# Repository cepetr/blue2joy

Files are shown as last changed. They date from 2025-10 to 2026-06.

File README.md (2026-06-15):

# 🕹️ Blue2Joy

**Blue2Joy** is an adapter that lets you use modern Bluetooth controllers with Atari 8-bit computers. It emulates **digital joysticks**, **analog paddles**, and supports **bidirectional communication** and much more. Try the live demo: https://cepetr.github.io/blue2joy/main.

While primarily intended for gamepads, the device is not limited to them - in principle, any BLE HID device, such as a keyboard or mouse, can be connected.

> Only devices that fully support the BLE HID over GATT Profile (HOGP) are supported. For this reason many older devices (especially gamepads) are unfortunately not usable with Blue2Joy. See [compatible devices](/doc/compatible-devices.md).

<div>
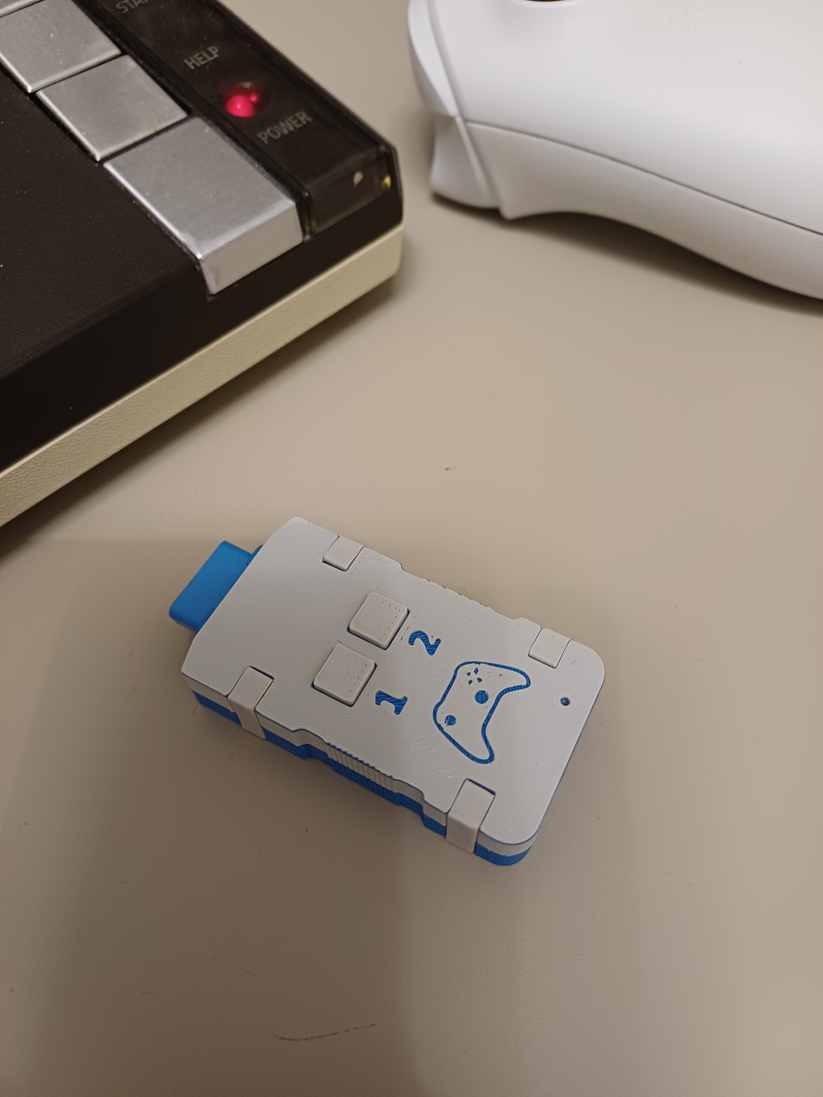
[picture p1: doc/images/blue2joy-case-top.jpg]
  
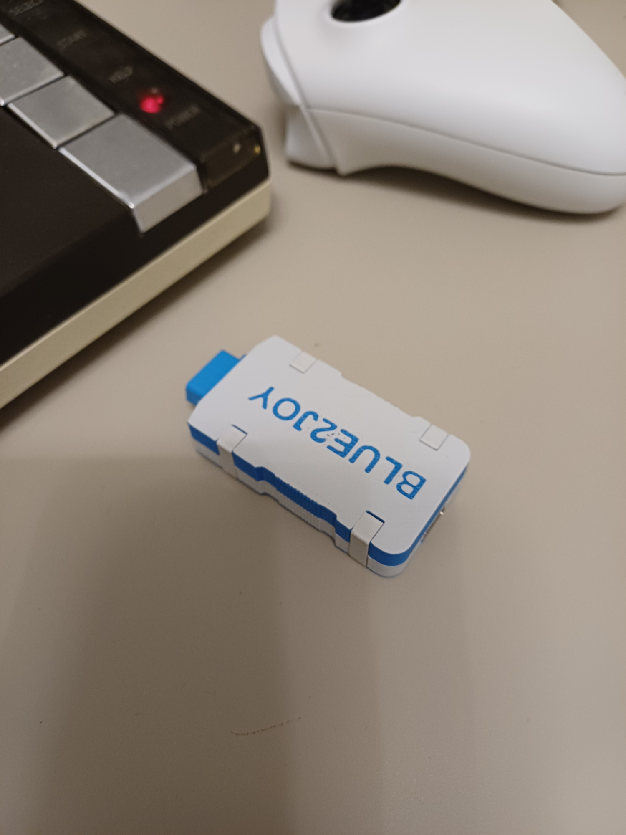
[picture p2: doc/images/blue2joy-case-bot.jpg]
  
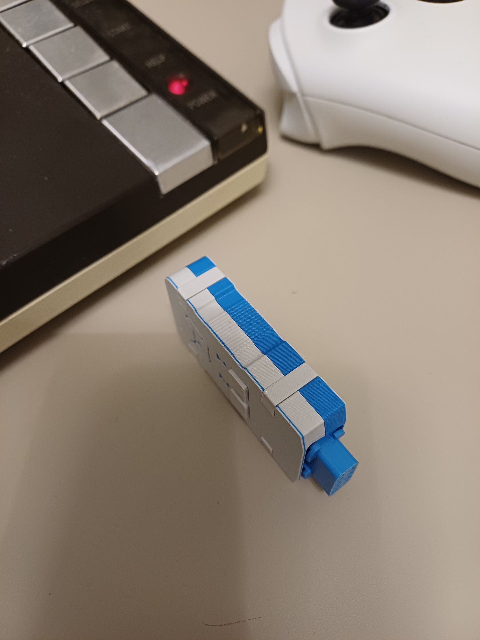
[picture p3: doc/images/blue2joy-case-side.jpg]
  
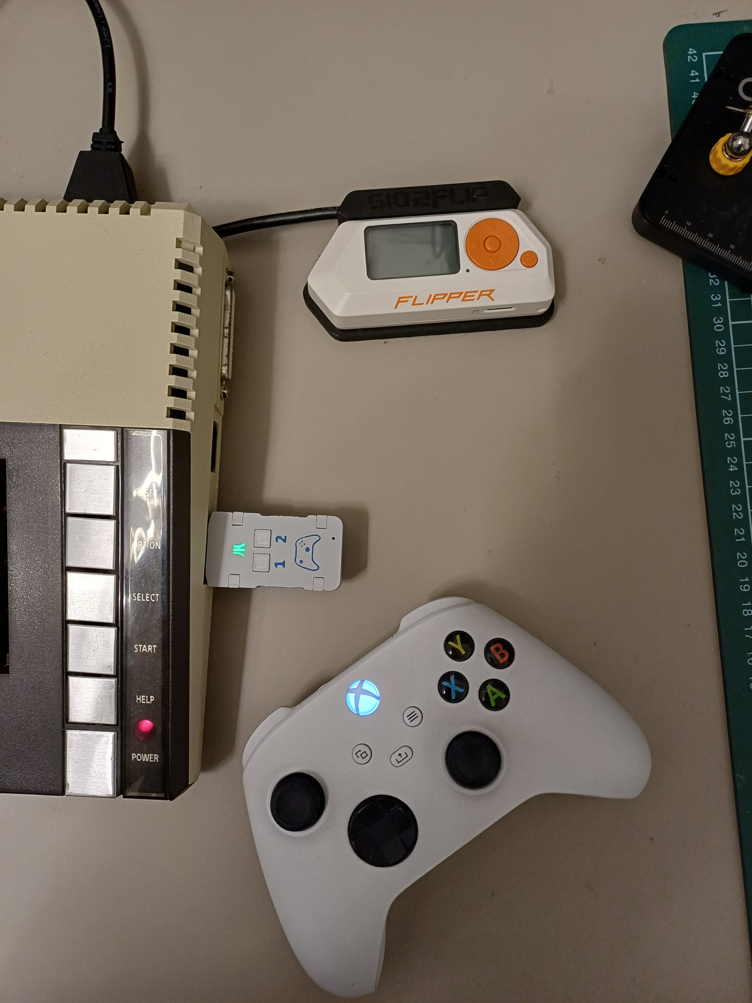
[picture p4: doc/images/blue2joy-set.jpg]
  
</div>

<div>
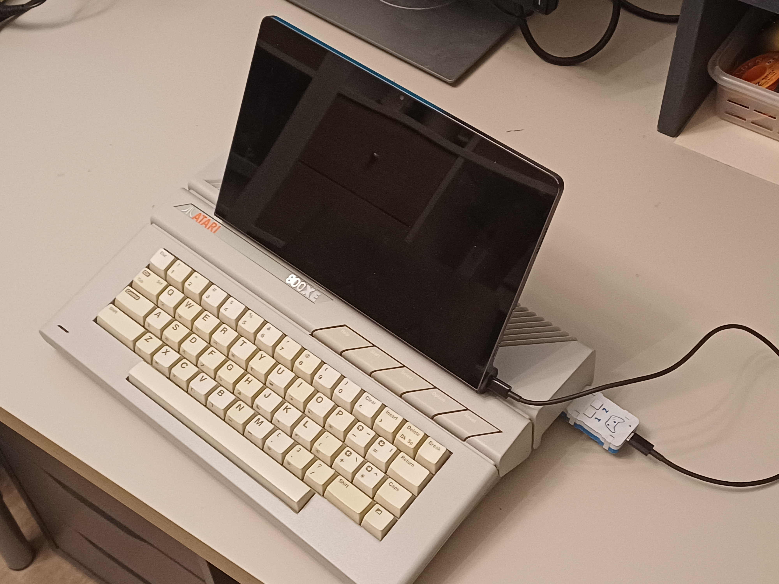
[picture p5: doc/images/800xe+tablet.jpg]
  
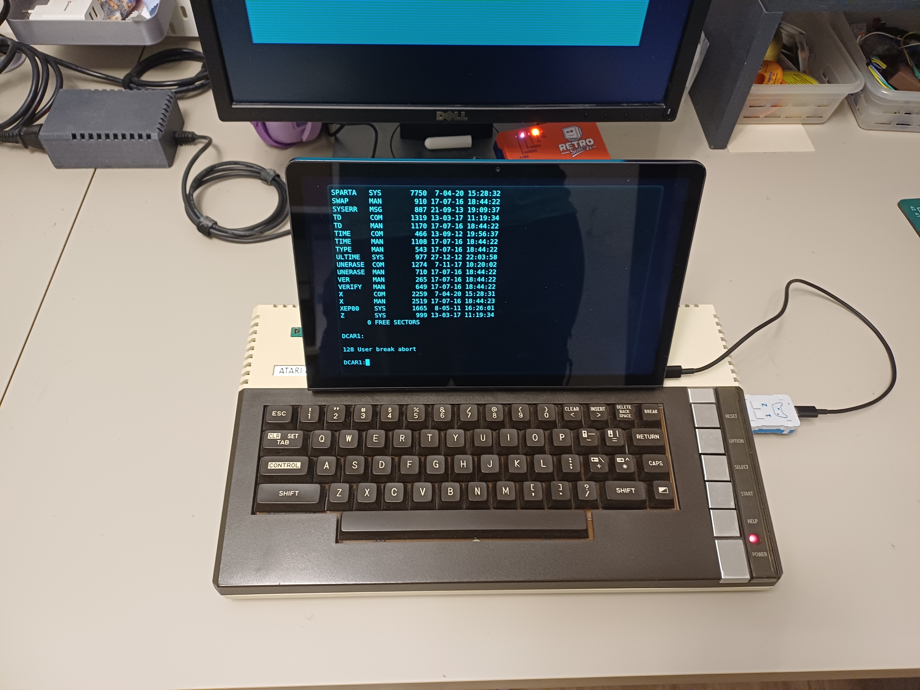
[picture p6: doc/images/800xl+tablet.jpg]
  
</div>

## Have a look at some demos:

(https://youtu.be/nXR6tCQPxGU)
(https://youtu.be/oCuMOWX2rxg)

## Use Cases
While there are other adapters that let Bluetooth controllers act as digital joysticks, Blue2Joy goes further. Besides standard and expected use cases, there are a few new possible ones that utilize analog input emulation or bidirectional communication:

- Use a gamepad as a digital joystick with up to 3 buttons (Joy2B+ standard)
- Use gamepad's analog sticks as paddles (direct or integration mode)
- Emulate paddles with a mouse
- Use a gamepad as an analog joystick (two axes on analog inputs) with up to 5 buttons
- Connect a mouse digitally- using quadrature encoding as on the Atari ST
- Connect a mouse in an analog way - using analog inputs for deltas, with up to 5 buttons
- Configure Blue2Joy via SPI-like communication over the joystick port
- Emulate the Y-axis of a light pen (conceptual idea, not sure if possible)
- Emulate an XEP80 terminal (work in progress)
- Send keycodes from the browser to Atari via paddle lines (used by the XEP80 terminal; requires [btjkbd.sys](/kbdrv/)).

Although designed for Atari 8-bit systems, Blue2Joy can be used with any device that follows the same joystick port pinout - with paddle functionality available only on Atari computers (see [details](/doc/paddle-emulation.md)).

## 🚧 Project Status

Blue2Joy is currently under active (but really slow) development. The hardware is stable and most of the core features have been successfully tested, but the software still needs some work to reach the level of polish I would consider complete.

## Repository Structure

This repository contains complete project documentation and source code for all Blue2Joy components shown in the following image.



### Blue2Joy Hardware
- Nordic nRF52840 (Cortex-M4F @ 64 MHz) with integrated Bluetooth 5 LE radio
- USB 2.0 Full-Speed (device mode only) for firmware updates, debugging, or use as a faster alternative to Bluetooth
- Female 9-pin D-sub connector
- RGB LED used as a status indicator (see [details](/doc/state-signalling.md))
- Two user push-buttons (see [details](/doc/button-functions.md))

For more details, see the [hardware](/hardware/) folder.

### Blue2Joy Firmware
- Supports pairing and connection to BLE HID devices (tested with Xbox Wireless Controller)
- Emulates a joystick port digital inputs as well as analog paddle potentiometers
- Supports bidirectional (SPI) communication with the Atari
- Indicates device status with an RGB LED
- Allows custom mapping of HID-device controls to joystick and paddle inputs
- Emulates an XEP80 terminal

For more details, see the [firmware](/firmware/) folder.

### Web Configuration
- A web application that allows you to configure the Blue2Joy device directly from any browser supporting the Web Bluetooth or Web USB standards
- Provides an easy way to configure the mapping of HID controls to joystick port digital and analog pins
- Allows you to configure the device even while it is connected to HID devices (e.g., gamepads, mice)
- Emulates an XEP80 terminal

The application is available at https://cepetr.github.io/blue2joy/main.

For more details, see the [webconfig](/webconfig/) folder.

### Atari Blue2Joy Keyboard driver
A driver for SpartaDOS that lets you use Blue2Joy as a keyboard. It can be used together with
XEP80 or on its own.

For more details, see the [atari](/atari/btjkbd) folder.

### Atari Blue2Joy Configuration Application
- Not implemented yet. This component currently exists only as a design intention.
- Intended to be an application that allows configuring the Blue2Joy device directly from Atari
- Planned to use the bidirectional (SPI-like) communication over the joystick port

For more details, see the [atari](/atari/btjmenu) folder.

## Feedback & Contributions

I'd be very happy to receive any feedback, pull requests, or even just a note that you've built and tried out Blue2Joy.

## License

This repository contains software, firmware, and hardware design files.

### Software and Firmware

All software and firmware files (in `atari/`, `firmware/` and `webconfig/`) are licensed under the GNU General Public License, version 3.

See [LICENSE-GPL](LICENSE-GPL) for details.

### Hardware

Schematics, PCB layout, mechanical design files (in `hardware/`) are licensed under the CERN Open Hardware Licence Version 2 - Strongly Reciprocal. You are free to use, modify, and share them, but if you distribute hardware or modified design files, you must also share your changes under the same license.

See [LICENSE-CERN](LICENSE-CERN) for details.

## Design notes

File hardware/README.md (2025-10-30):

# 🔧 Blue2Joy — hardware

This folder contains the **KiCad** project and 3D design files for the Blue2Joy adapter:

* [`electronics/`](/hardware/electronics/) - KiCad project
* [`mechanical/`](/hardware/mechanical/) - 3-D model of the device’s enclosure

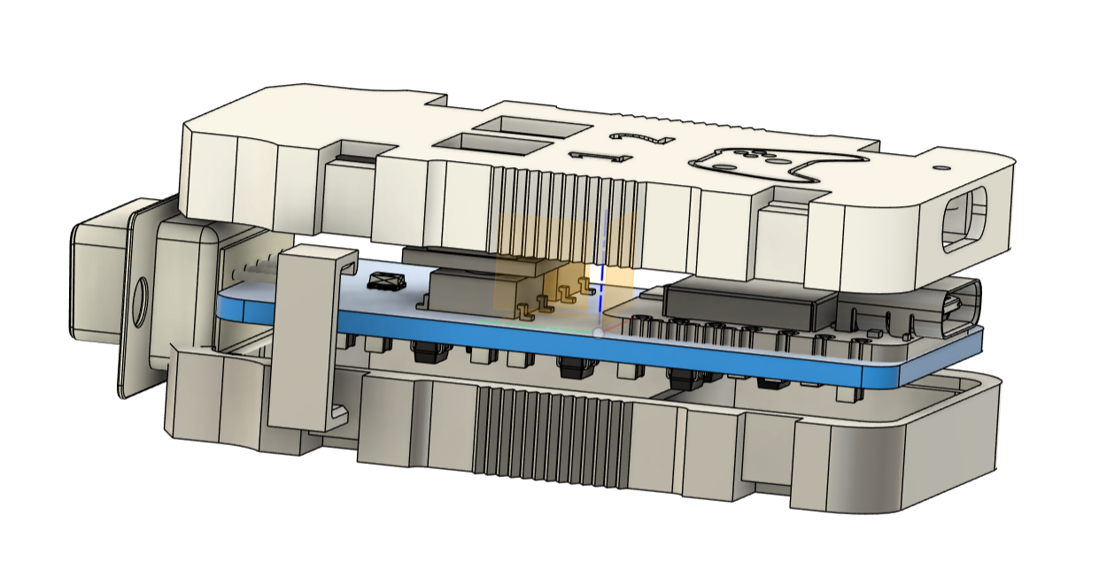
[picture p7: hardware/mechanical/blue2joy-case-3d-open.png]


## Schematic & BOM

The design uses readily available SMD components and a XIAO nRF52840 module to keep the total cost and assembly complexity relatively low.

Schematic in PDF format is available [here](/hardware/electronics/fab_v1e/blue2joy-v1e.pdf)

The estimated parts cost is roughly USD 25, depending on the supplier and any volume discounts.

| # | Qty| Reference | Package |Part Numbers |
|----|---|---|---|---|
| 1  | 1 | U1 | | XIAO nRF52840 Plus |
| 2  | 1 | U2 | SOT-23-5 | TPS73133DBV |
| 3  | 2 | U3, U5 | SOT-23-6 | 74LVC2G17DBV |
| 4  | 3 | U4, U7, U8 | SOT-23-6 | 74LVC2G07DBV |
| 5  | 1 | U6 | SOT-23-5 | TLV9001IDBV |
| 6  | 1 | U9 | SOT-23-5 | XC8110AA01MR |
| 7  | 1 | U10 | SOT-23-6 | 74HCT2G34GV |
| 8  | 2 | Q1, Q3 | SOT-23-3 | BSS138 |
| 9  | 2 | Q4, Q5 | SOT-23-3 | SI2323DDS |
| 10 | 1 | J1 | - | DE9 Socket (Male)  |
| 11 | 2 | SW1, SW2 | - | OMRON B3FS-1010 |
| 12 | 1 | D1 | 2020 | WS2812-2020 |
| 13 | 8 | R1, R2, R3, R13, R14, R15, R18, R19 | 0805 | 10kΩ/125mW |
| 14 | 2 | R6, R10 | 0805 | 100kΩ/125mW |
| 15 | 4 | R8, R9, R11, R12 | 0805 | 18kΩ/125mW |
| 16 | 5 | R20, R21, R22, R23, R24 | 0805 | 820Ω/125mW |
| 17 | 2 | R4, R17 | 0805 | 1.8kΩ/125mW |
| 18 | 2 | R5, R16 | 0805 | 2.2kΩ/125mW |
| 19 | 4 | C1, C2, C3, C4 | 0805 | 1µF |
| 20 | 1 | C5 | 0805 | 10µF |
| 21 | 3 | C6, C7, C8 | 0805 | 100nF |

## PCB

The [`electronics/fab_v1d`](/hardware/electronics/fab_v1d/) folder contains the manufacturing files for the latest PCB revision.

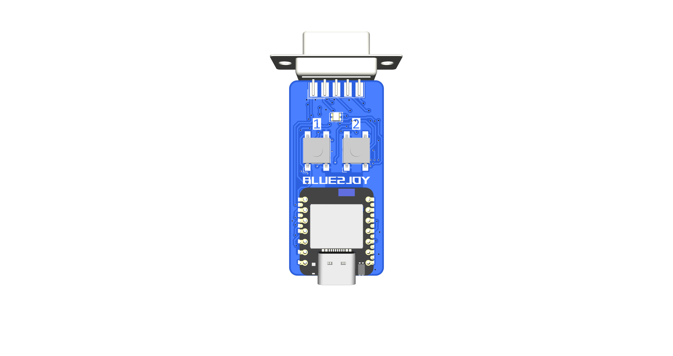
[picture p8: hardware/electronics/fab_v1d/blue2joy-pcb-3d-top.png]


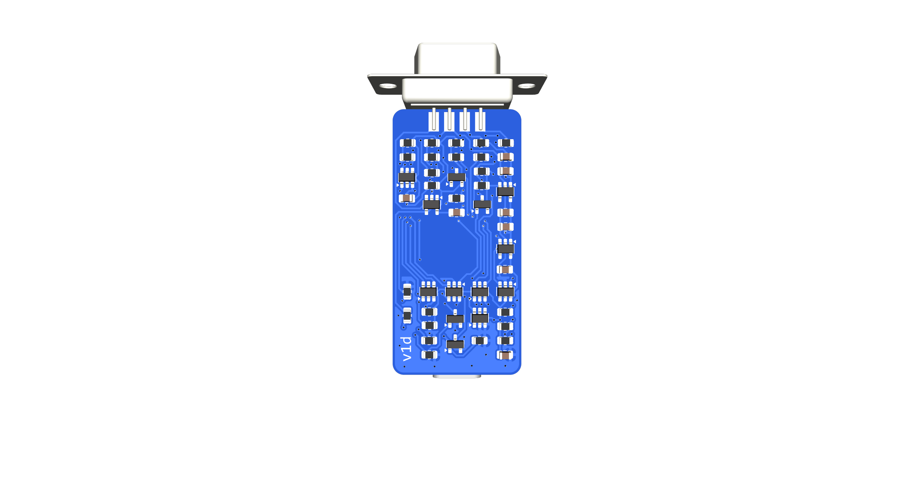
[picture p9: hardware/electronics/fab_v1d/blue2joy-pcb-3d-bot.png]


## Assembly notes

Building the board **does require basic SMT soldering skills**.
If you have never worked with solder paste or hot air before, expect a small learning curve - nothing close to rocket science, but still a step up from through-hole work.

| Part type | Package | Difficulty (subjective) |
|---|---|---|
| Passives  | **0805** | easy; forgiving |
| Logic & power | **SOT-23-x** | fine for hot-air or drag solder, **be extra careful with orientation - SOT-23-6 parts have a tiny, barely visible dot marking pin 1** |
| MCU module | **XIAO nRF52840 Plus** (castellated) | can be hand-soldered with a fine-tip iron |
| RGB LED | **WS2812C-Mini** | the smallest part; watch orientation |

After assembly, verify that there are no shorts between pins on the SOT-23-x packages.

## DE9 Socket

DE9 (Cannon) connectors are manufactured only with a metal housing. After cutting along the edge, the plastic part can be popped out like a nut. However, the plastic parts differ between manufacturers, and in some cases, they need to be glued together.

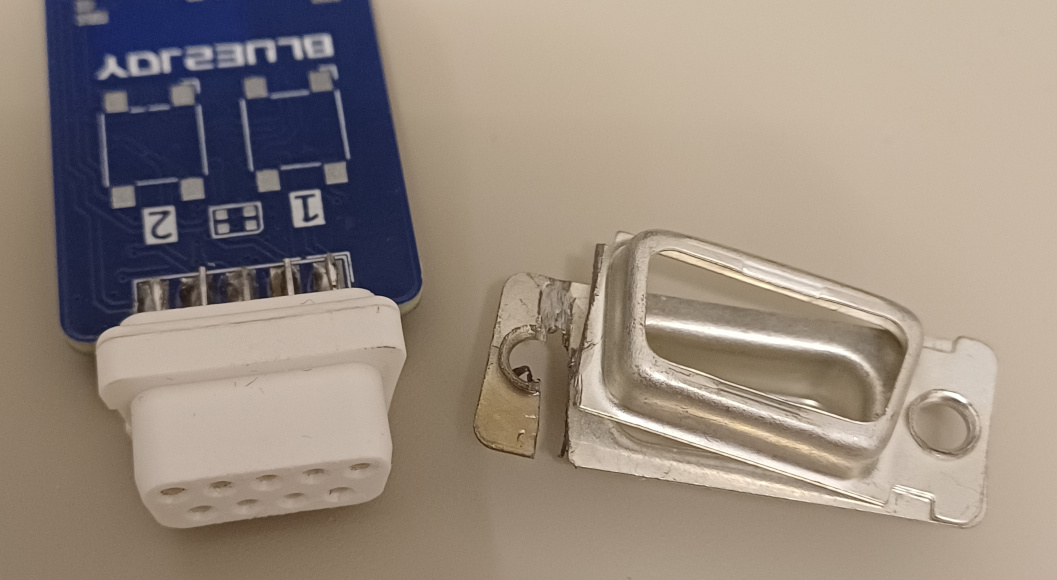
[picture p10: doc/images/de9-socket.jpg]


## Hardware Status & Disclaimer

Although the device has been tested with three Atari models (800XL, 800XE, and 600XL - all PAL), hidden design flaws may still exist. Use all design files, instructions, and the board at your own risk; no warranties or guarantees are implied.

The plastic parts were printed from PLA (standard 0.4 mm nozzle, 0.2 mm layer height, 30% infill) on a Prusa Mk3 printer. The tolerances are quite tight, so it’s likely that on a different printer or with another material, there may be issues fitting the parts together.

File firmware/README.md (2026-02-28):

# Blue2Joy — nRF52 Firmware

For more information about the firmware, see [documentation](/doc/fw-architecture.md).

## 🗲 How to Flash

If you just want to flash your device and don’t feel like building from source, grab the pre-built binaries on the project’s [Releases](https://github.com/cepetr/blue2joy/releases) page.

- Double-press RESET button => board appears as XIAOBOOT mass-storage.
- Copy `blue2joy.uf2` to that drive.
- The XIAO reboots automatically into your new firmware.

## 🛠️ How to Build

### Prerequisites
- Git ≥ 2.30
- Python 3.8 – 3.12 (for west and Python-based scripts)
- ~10 GB free disk space

### Build steps

1. Install nrfutils

    ```shell
    pip install --upgrade nrfutil
    ```

    see https://docs.nordicsemi.com/bundle/nrfutil/page/guides/installing.html

2. Install the Toolchain Manager

    ```shell
    nrfutil install toolchain-manager
    ```

    This is a small helper that downloads and maintains pre-built Zephyr + GNU Arm toolchains.

3. Download nRF Connect SDK v3.0.1

    ```shell
    nrfutil toolchain-manager install --ncs-version v3.0.1
    ```

4. Start a shell that knows the toolchain

    Folder layout after installation (Linux/macOS default):

    ```
    ~/ncs/v3.0.1/
    ├── toolchain/
    └── zephyr/      <- Zephyr RTOS & modules
    ```

5. Launch shell

    ```shell
    nrfutil toolchain-manager launch --shell
    # then inside the launched shell:
    source ~/ncs/v3.0.1/zephyr/zephyr-env.sh
    ```

6. Build the firmware

    Navigate to your project root (where west.yml lives or the sample you cloned) and run:

    ```shell
    west build -b xiao_ble/nrf52840 --no-sysbuild
    ```

    When the build finishes, the UF2 image will be at `build/zephyr/zephyr.uf2`.

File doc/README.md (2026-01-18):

# 📖 Blue2Joy — Documentation

Definitely not complete, but at least some documentation 🙂.

- [Profile examples](profile-examples.md)
- [Compatible Devices](compatible-devices.md)
- [Paddle Inputs Emulation](paddle-emulation.md)
- [Button Functions](button-functions.md)
- [State Signalling](state-signalling.md)
- [Firmware Architecture](fw-architecture.md)
- [Power & Ground Safety](ground-safety.md)

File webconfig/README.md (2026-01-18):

# 🌐 Blue2Joy Web Configuration

A web application that allows you to configure Blue2Joy directly from any browser supporting the Web Bluetooth standard.

It provides an easy way to configure the mapping of HID controls to joystick port digital and analog pins.

Application communicates with Blue2Joy over Bluetooth, even while it is connected to HID devices (e.g., gamepads, mice).

<div>
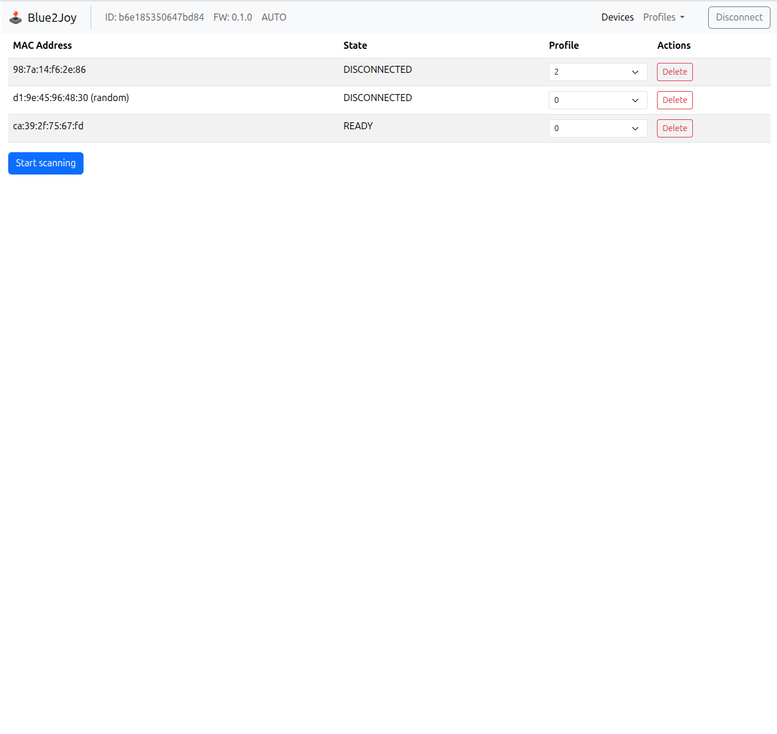
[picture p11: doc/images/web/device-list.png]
  
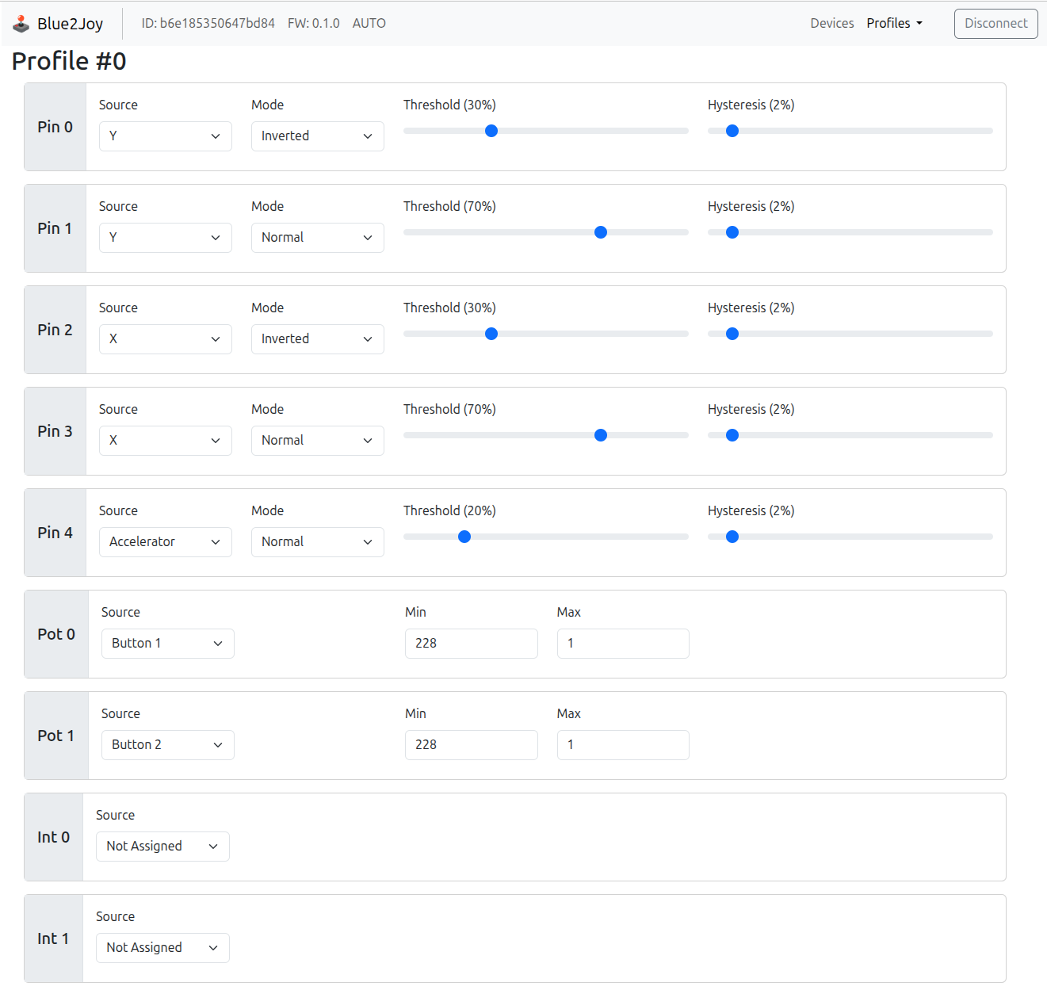
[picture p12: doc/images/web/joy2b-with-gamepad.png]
  
</div>

# How to build

You don't neeed to build anything. Just go to
https://cepetr.github.io/blue2joy/main

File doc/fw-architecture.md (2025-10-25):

# Firmware architecture



#### bthid
- Discovers BLE HID devices
- Establishes connections with BLE HID devices
- Processes HID device capabilities and periodic reports

#### devmgr
- Manages connections with HID devices
- Loads and stores persistent device configurations
- Signals connection and disconnection events

#### mapper
- Maps HID device controls to joystick port inputs
- Loads and stores persistent mapping configurations

#### btsvc
- Handles BLE connection for Blue2Joy configuration

#### io/joystick & io/paddle
- Emulates digital joystick I/O and analog potentiometers

#### io/spislave
- Provides SPI connection with Atari 8-bit computers

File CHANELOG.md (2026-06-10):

# Changelog

### Unreleased
### Fixed
- Implemented XEP80 character and cursor blinking (currently text mode only)
- Fixed XEP80 character deletion within logical lines, with correct cross-row shifting and cleanup of empty wrapped rows.

### v0.5.1
### Fixed
- Added WinUSB auto-binding for WebUSB via MS OS 2.0 BOS; no Zadig/INF needed.

## v0.5.0
### Fixed
- Web USB stability improvements

## v0.4.0
### Added
- Web USB support (alternative to Web Bluetooth)
- Zephyr shell support and improved logging

## v0.3.0
### Added
- XEP80 emulator (not yet complete)
- Demo mode for testing and demonstration purposes
- Light and dark themes

### Fixed
- Improved POT emulation accuracy and reduced jitter
- Numerous stability improvements

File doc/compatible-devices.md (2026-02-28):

# Compatibility List

Only devices that fully support the BLE HID over GATT Profile (HOGP) are supported.

Devices that rely on Bluetooth Classic are not supported, because the nRF52840 MCU supports only Bluetooth Low Energy (BLE) and does not implement Bluetooth Classic.

For this reason many devices (especially gamepads) are unfortunately are not usable with Blue2Joy.

> Although I only discovered this limitation after the project was already underway, working on it has been both enjoyable and a great learning experience. I plan to keep developing the project by extending the existing web configuration app to act as a bridge, allowing virtually any gamepad connected to a PC to be used. I decided to publish the project in its current form because it already demonstrates useful ideas and has clear potential to grow into a more flexible and capable solution.

The following table lists the devices that were tested.

| Device | Model | Firmware | Compatible | Notes |
|---|---| ---|---|---|
| XBOX Wireless Controller | 1914  | 5.23.6 | Yes | |
| C-Tech Mouse | WLM12-GR  | SVN1754_V93 | Yes |  |
| 8BitDo Zero 2 | | | No  |  |
| Sony Dual Sense | CFI-2C11W | | No |
| HP 425 Bluetooth Mouse | TPA-P006M | | Yes |

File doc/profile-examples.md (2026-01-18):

# Examples of Profile Settings

HID controller inputs can be mapped to joystick port pins using profiles. Multiple profiles may be defined and assigned to specific controllers, uniquely identified by their MAC addresses. When a controller is connected, Blue2Joy automatically selects the correct profile.

**Digital and Analog Inputs**

The joystick port provides five digital and two analog inputs. Each input can be mapped to either a button or an analog stick. Button inputs support inversion. Analog stick inputs support configurable threshold, hysteresis, and optional inversion.

**Integrators and encoders**

Each profile can define two virtual integrators or quadrature encoders for processing relative inputs, such as mouse movement on the X and Y axes or integrated gamepad stick deflection.

Integrator positions can be mapped to analog pins, while quadrature encoder outputs can be mapped to digital pins.

## Joy2B+ Emulated by Gamepad Joystick



## Joy2B+ Emulated by Gamepad Hat Switch

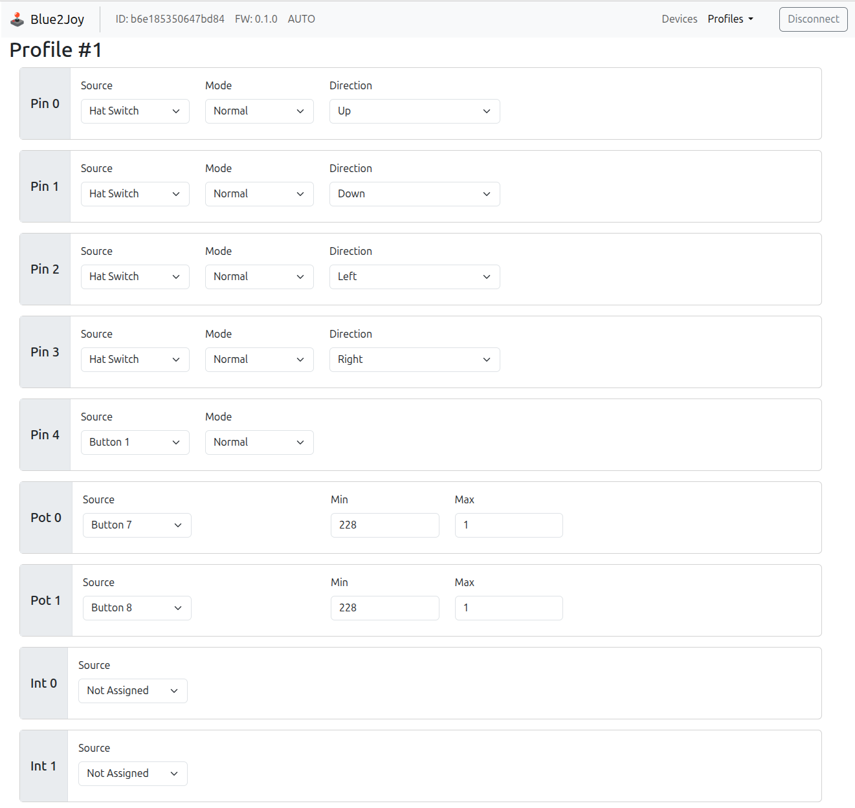
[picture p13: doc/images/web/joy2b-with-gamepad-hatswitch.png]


## ST Mouse Emulated by Mouse

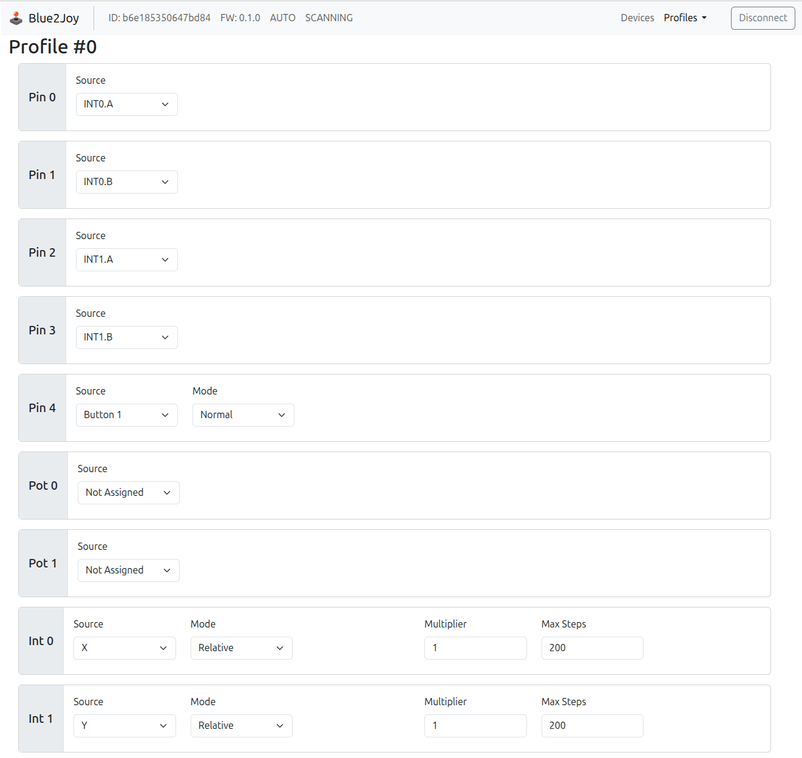
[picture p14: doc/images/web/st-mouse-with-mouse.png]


## ST Mouse Emulated by Gamepad Joystick

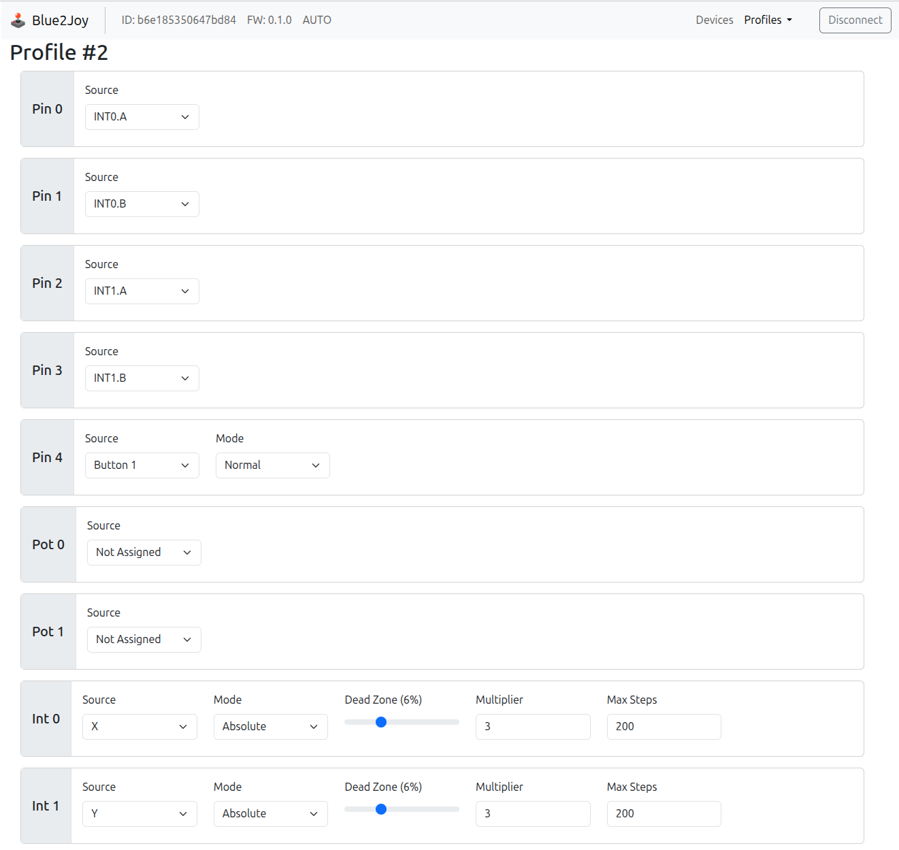
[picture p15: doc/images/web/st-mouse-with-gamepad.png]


## Paddle Emulated by Gamepad Joystick (Arkanoid Version)

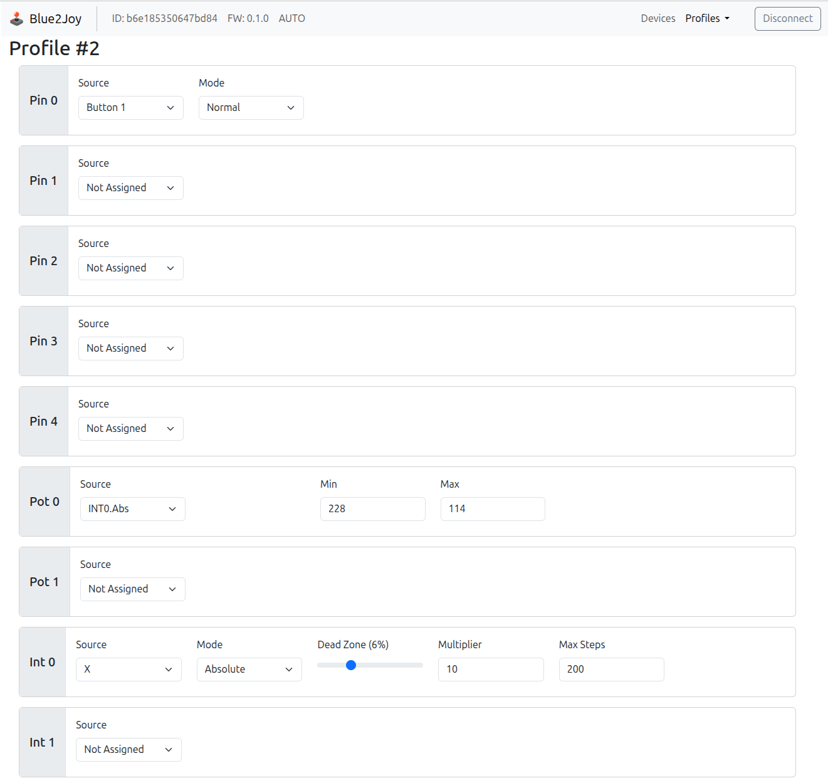
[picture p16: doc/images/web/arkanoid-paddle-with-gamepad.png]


## Paddle Emulated by Mouse (Arkanoid Version)

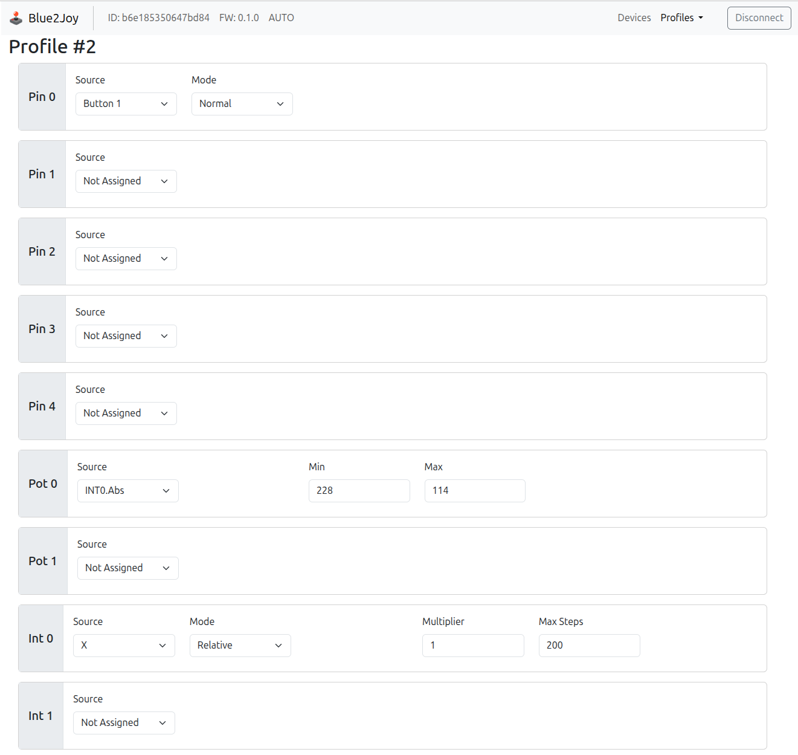
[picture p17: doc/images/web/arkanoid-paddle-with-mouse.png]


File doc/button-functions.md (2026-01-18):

# Buttons Function

There are two buttons on the device, labeled 1 (left) and 2 (right).

| Action | Function |
|---|---|
| Hold both buttons during power-up |Perform a factory reset |
| Press left button | Disconnect the current HID device and start scanning for known devices |
| Hold left button for 2 seconds | Disconnect the current HID device and start scanning, accepting new HID devices (pairing mode) |
| Press right button | Start or stop advertising (allow connections from the Web Configurator) |

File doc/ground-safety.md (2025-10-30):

# Note on Power & Ground Safety
The Blue2Joy adapter includes reverse-current protection, allowing 5V rail can be powered at the same time from both the Atari joystick port and USB without either source back-feeding the other.

Ground, however, still matters. The setup is normally safe as long as all device shares the same ground reference - for example, when everything is plugged into the same power strip.

**Beware of ground loops!**

If the Atari, PC, or other gear are connected to different outlets, their return paths can form a loop that leads to data noise, circulating currents between grounds, and, in rare cases, hardware damage.

* Whenever you can, plug all equipment into the same strip.
* A laptop running on battery has a “floating” ground and greatly reduces the risk of loops.

Typical workflows:
* USB debugging - keeping both cables attached is fine; just follow the grounding advice above.
* Firmware flashing - the Atari doesn’t need to stay connected while flashing, so disconnect it to avoid any potential conflicts.

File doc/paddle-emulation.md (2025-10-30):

# How paddle input works

Paddle controllers use 1 MΩ potentiometers to charge an RC network (1.8 kΩ, 47 nF) located inside the 8-bit Atari system. This network is connected to the POTx inputs of the POKEY chip. The POKEY chip contains discharge (dump) transistors, eight 8-bit latches, and a binary counter that counts up to 228, driven by ~16kHz clock signal.

The measurement cycle begins when the CPU writes to the `POTGO` register. This action:
- resets the counter,
- starts it counting,
- releases the dump transistors, allowing the external capacitors to charge through the paddle potentiometers.

As each POTx input reaches a logical high level, the current counter value is latched into the corresponding POTx register, where it can later be read by the CPU.

If the counter reaches 228, regardless of whether a logical high is detected on a POTx input, it:

- stops,
- re-engages the dump transistors,
- discharges the capacitors.

POTx acquisition and writing to the `POTGO`register are handled in the VBI interrupt handler at 50/60 Hz.

The following pictures show the voltage on the paddle input (on the joystick port) for two different resistances:

| 27kΩ (POT0=13) | 270kΩ (POT0=121) |
|---|---|
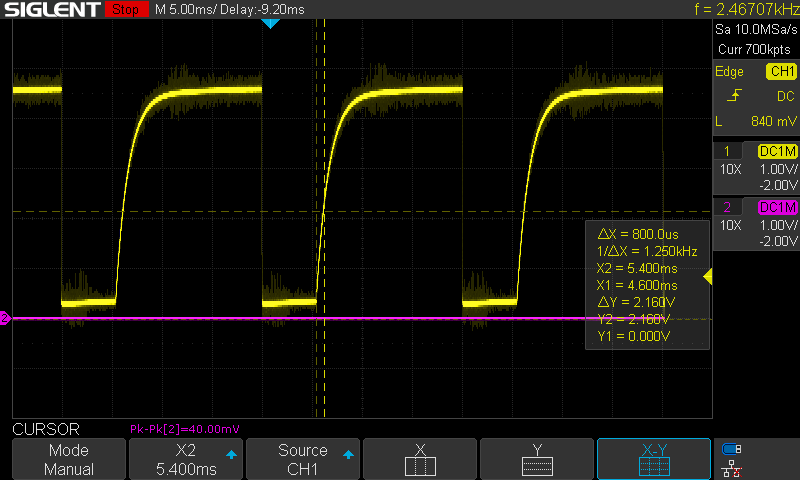
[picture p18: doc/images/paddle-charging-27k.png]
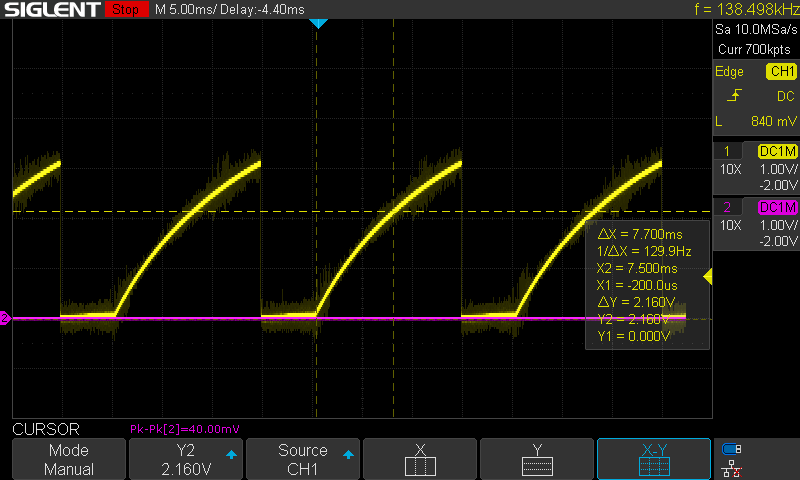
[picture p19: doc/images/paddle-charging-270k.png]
|  |  |

# How paddle emulation works

This design uses neither an analog nor a digital potentiometer. Instead, it relies on precise timing: 5 V is applied to the paddle input exactly when the 47 nF capacitor must be charged. Achieving this requires detecting the precise instant the POKEY chip turns off its discharge transistor and starts a new measurement cycle.

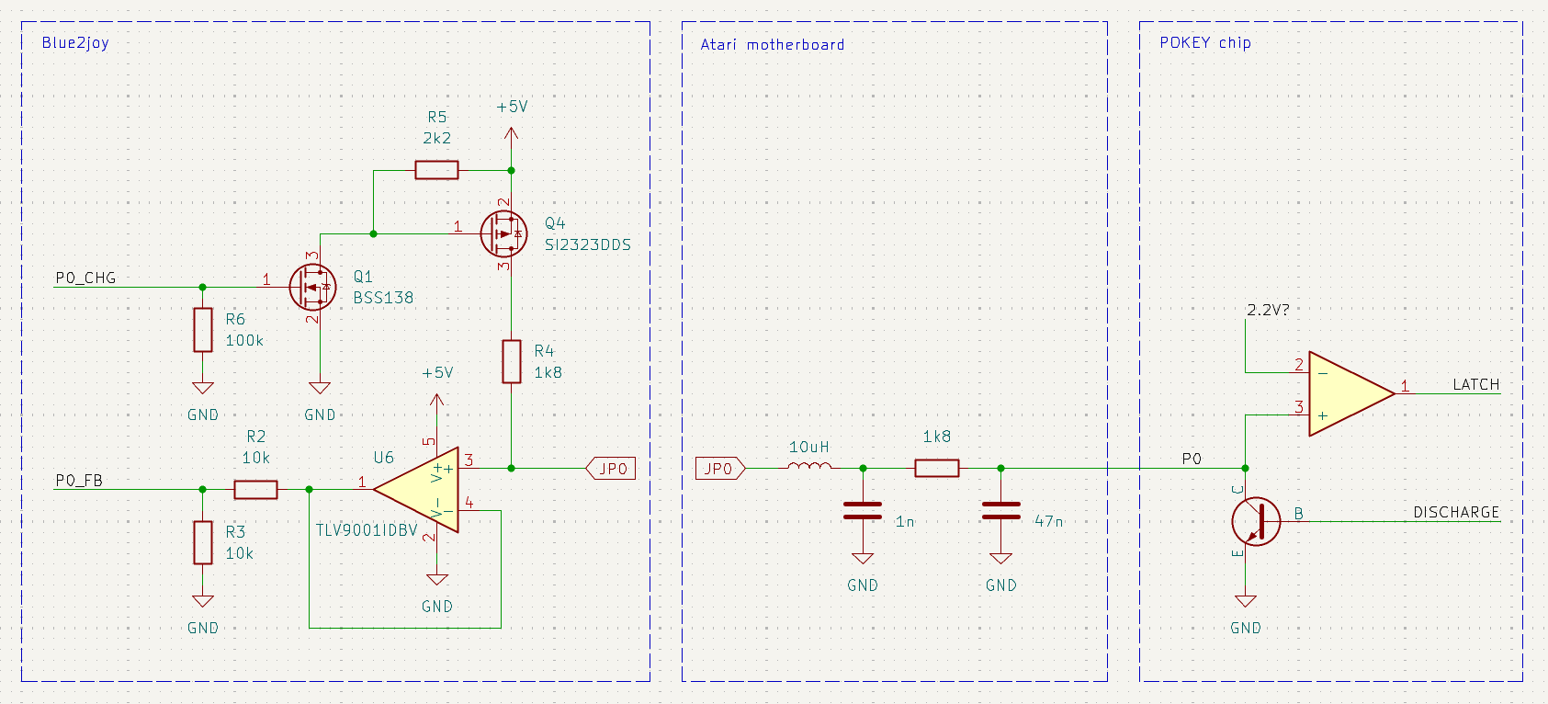
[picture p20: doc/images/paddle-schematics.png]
Schematics


Detecting the moment the transistor engages (when the capacitor is forced to ground) would be easier, but it provides little value—we still would not know when the VBI handler writes to POTGO, so we could not time the charge pulse accurately.

To sense the transistor’s release, we bias the paddle input through a 1.8 kΩ resistor with 5 V. While the discharge transistor is active, the pin settles at ~2.5 V. As soon as POKEY releases the transistor, the voltage on POTx rises rapidly. This transition must be detected within a few microseconds, and the bias must be removed immediately so the capacitor is not prematurely charged past the logic-high threshold.

Once the release is detected, we can schedule a precisely calibrated delay before re-applying 5 V to the POTx pin to drive the capacitor to 5 V in one shot. The delay is quantized in 64 µs increments (1/16kHz), directly corresponding to the current count value of POKEY’s internal counter.

Because all timing is handled entirely in hardware - without any CPU intervention - the result is highly precise and introduces minimal jitter. To achieve this, we utilize one on-chip comparator with a 64-level selectable threshold, one hardware timer per POTx input, GPIOTE for charge control, and PPI to interconnect these peripherals into a tightly synchronized system.

❷ **Trigger:** When the POKEY chip releases its discharge transistor, the on-chip comparator (COMP) detects the capacitor voltage crossing approximately 1.4 V and generates a single `COMP_UP` event.

❸ **Synchronise:** The `COMP_UP` event is routed via PPI to both `TIMER2.CLEAR` (1 MHz, 16-bit) and `GPIOTE_CLR(POT0)`. This marks the zero-time reference for the scan and ensures that the capacitor is no longer being actively charged.

❸-❹ **Time-shift:** A value written by software to `TIMER2.CCx`, calculated as 64 µs × v (where v = 1..228), defines the precise delay corresponding to the desired POKEY counter value.

❹-❶ **Drive caps:** When a `CCx` compare match occurs, PPI triggers `GPIOTE_SET(POT0)`, briefly enabling a P-MOSFET to apply 5 V to the paddle input. This action synthesizes the RC charge delay that POKEY measures. The 5 V level is held on the POTx line until the next scan cycle to allow detection of the next discharge-release event by the comparator.

Since all POKEY POTx inputs are sampled synchronously, the timing for POT1 channel is derived from the measurement on POT0.

The following pictures show the voltage on the paddle input (on the joystick port) for two different timer compare register values, emulating two different POT0 values:

| POT0=32 | POT0=192 |
|---|---|
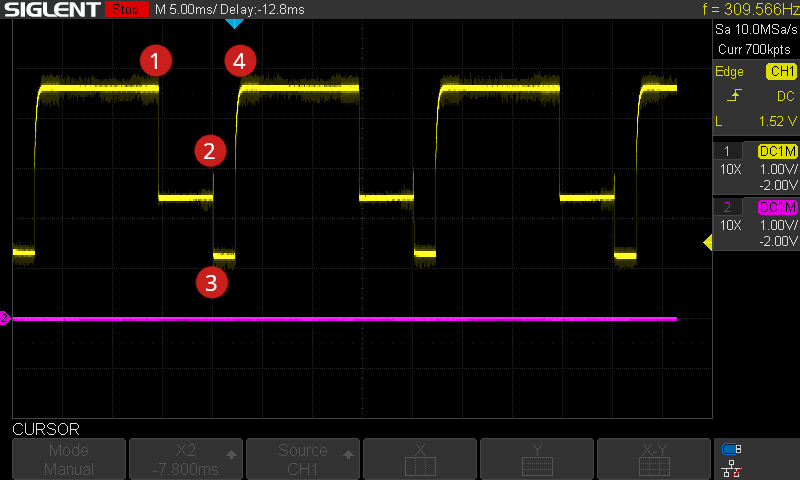
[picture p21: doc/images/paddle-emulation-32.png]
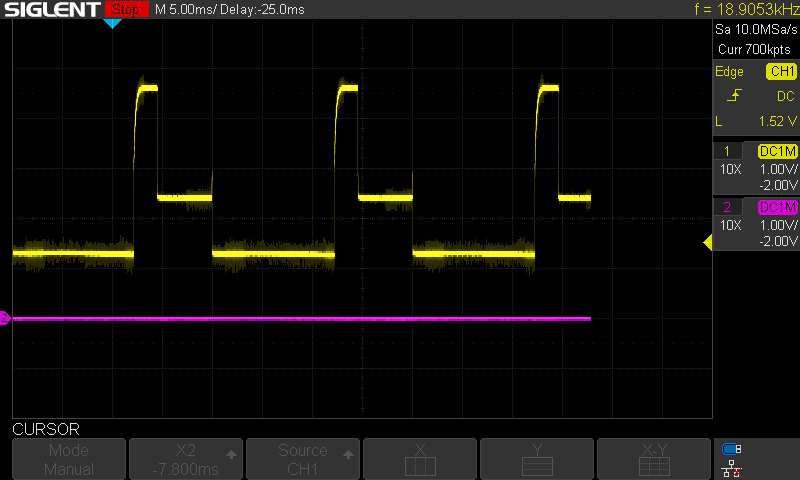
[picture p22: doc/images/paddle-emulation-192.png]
|  |  |

## Limitations

The proposed control method, along with the current circuit (with the 1.8 kΩ resistor in place), slightly limits the minimum time in which the capacitor can be charged. As a result, it is currently not possible to emulate all values in the 1-228 range, only 2-228. This could probably be addressed somehow, but at the moment I don't consider it critical.

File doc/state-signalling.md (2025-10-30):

# RGB LED Status Indicators

The RGB LED signals various states and events using different colors and blink patterns:

| State | RGB LED |
|---|---|
| General error | 🔴 Blinks red 3x|
| Factory reset | 🟡 Blinks yellow 3x|
| Scanning | 🔵 Blue fades in and out slowly|
| Scannig + Pairing  | 🔵 Blue fades in and out|
| Advertising | 🔵 Fast blue blinking|
| Connecting to device | 🟢 Fast green blinking |
| Connected to device | 🟢 Solid green |

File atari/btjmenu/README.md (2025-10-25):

# Blue2Joy — Atari 8-bit software

An unfinished software for the Atari, intended for configuring and testing the Blue2Joy hardware.

## 🛠️ How to Build

> If you don’t feel like building from source, grab the pre-built binariy on the project’s [Releases](https://github.com/cepetr/blue2joy/releases) page.

### Prerequisites

The 8-bit software is written in C using [clang/llvm-mos](https://llvm-mos.org/wiki/Welcome). All required tools and SDK paths are declared in [`shell.nix`](atari/shell.nix).

Install the Nix package manager by following the instructions at [https://nixos.org/download](https://nixos.org/download).

### Build steps

1. **Enter the development shell**

   ```sh
   nix-shell
   ```

2. **Configure the build**

   ```sh
   cmake -B build -G Ninja
   ```

3. **Build the project**

   ```sh
   cd build
   ninja
   ```

   The resulting Atari binary will appear inside the build directory.

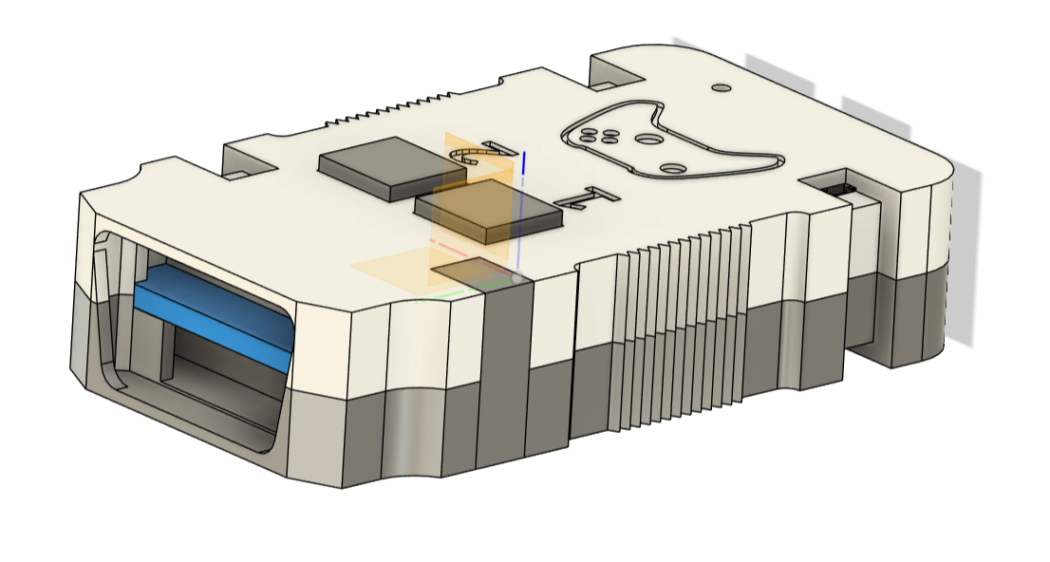
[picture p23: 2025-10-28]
hardware/mechanical/blue2joy-case-3d.png

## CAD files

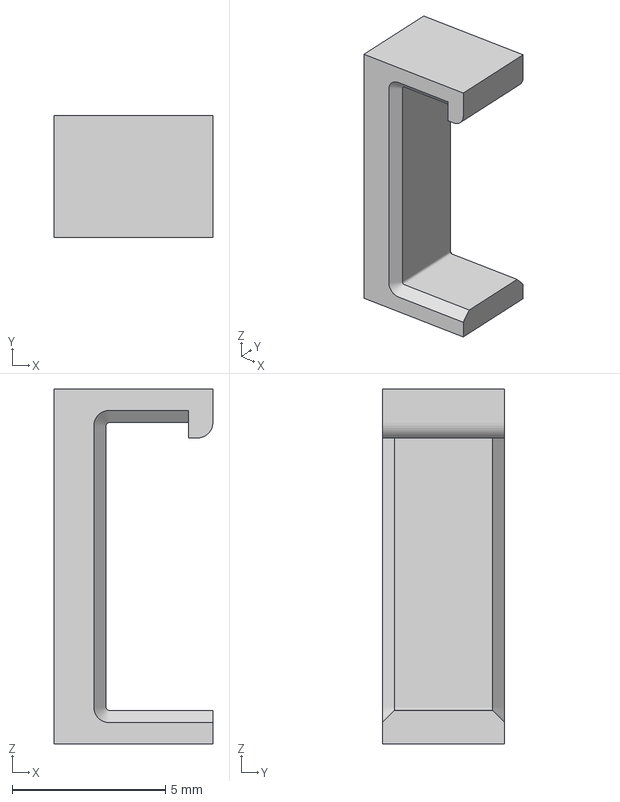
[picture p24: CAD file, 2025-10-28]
hardware/mechanical/blue2joy_clamp_v1.3mf
5.19 x 4.00 x 11.6 mm

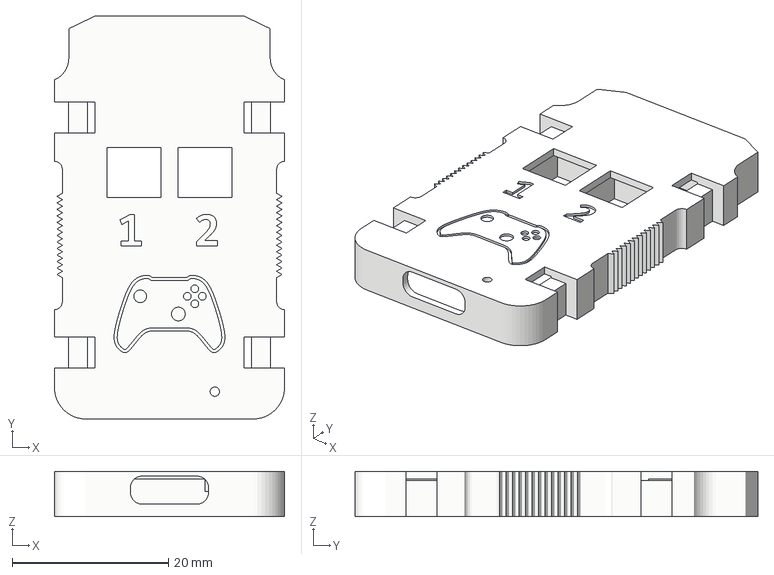
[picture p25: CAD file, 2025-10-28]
hardware/mechanical/blue2joy_lid_v1.3mf
29.4 x 51.6 x 5.80 mm

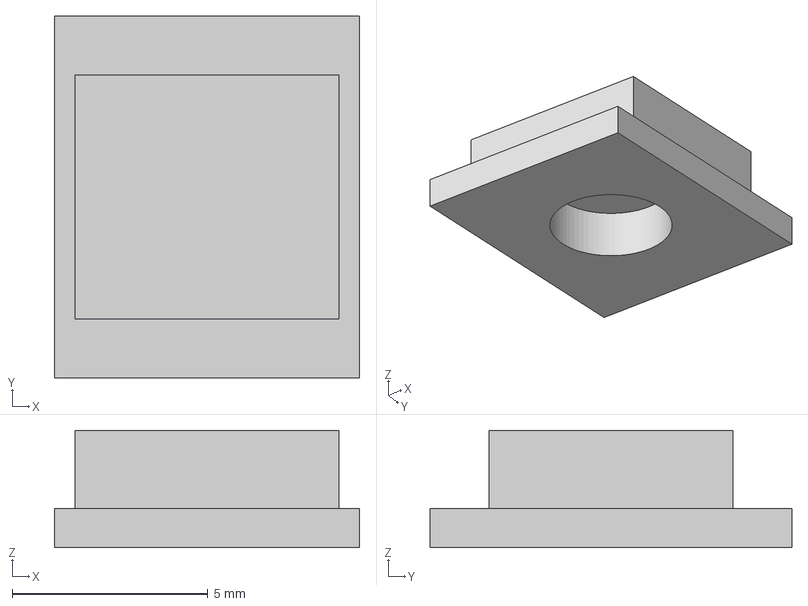
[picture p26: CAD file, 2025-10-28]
hardware/mechanical/blue2joy_button_v1.3mf
7.80 x 9.25 x 3.00 mm

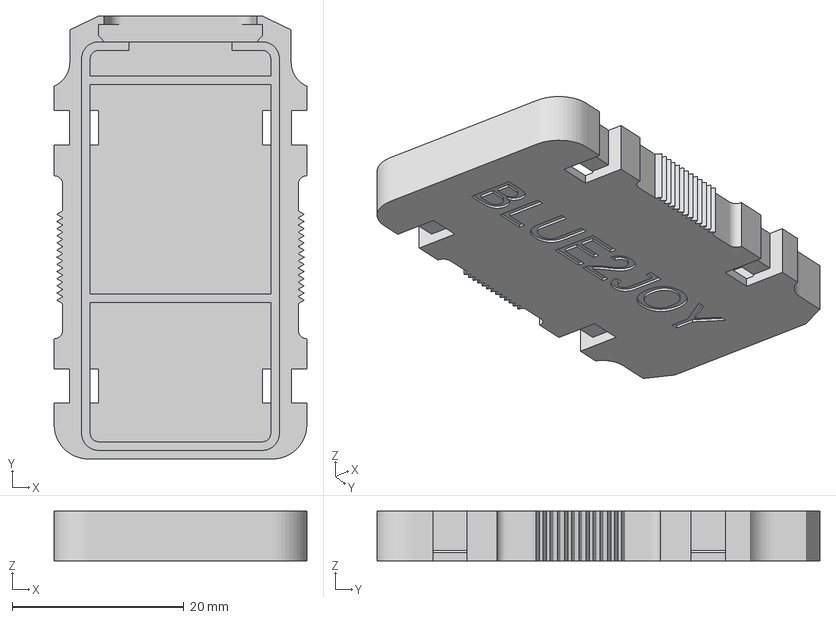
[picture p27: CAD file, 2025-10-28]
hardware/mechanical/blue2joy_base_v1.3mf
29.4 x 51.6 x 5.80 mm

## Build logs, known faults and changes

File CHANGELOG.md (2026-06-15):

# Changelog

### v0.6.0
### Added
- Added XEP80 character and cursor blinking (text mode only for now).
- Added browser-to-Atari keycode input over paddle pins (requires btjkbd.sys on the Atari side).
- Added support for Bluetooth devices using resolvable private addresses
### Fixed
- Fixed XEP80 character deletion within logical lines, with correct cross-row shifting and cleanup of empty wrapped rows.
- Improved reliability of USB connection (fixed session/event handling bugs).
- Fixed LED signalling in manual mode.

### v0.5.1
### Fixed
- Added WinUSB auto-binding for WebUSB via MS OS 2.0 BOS; no Zadig/INF needed.

## v0.5.0
### Fixed
- Web USB stability improvements

## v0.4.0
### Added
- Web USB support (alternative to Web Bluetooth)
- Zephyr shell support and improved logging

## v0.3.0
### Added
- XEP80 emulator (not yet complete)
- Demo mode for testing and demonstration purposes
- Light and dark themes

### Fixed
- Improved POT emulation accuracy and reduced jitter
- Numerous stability improvements

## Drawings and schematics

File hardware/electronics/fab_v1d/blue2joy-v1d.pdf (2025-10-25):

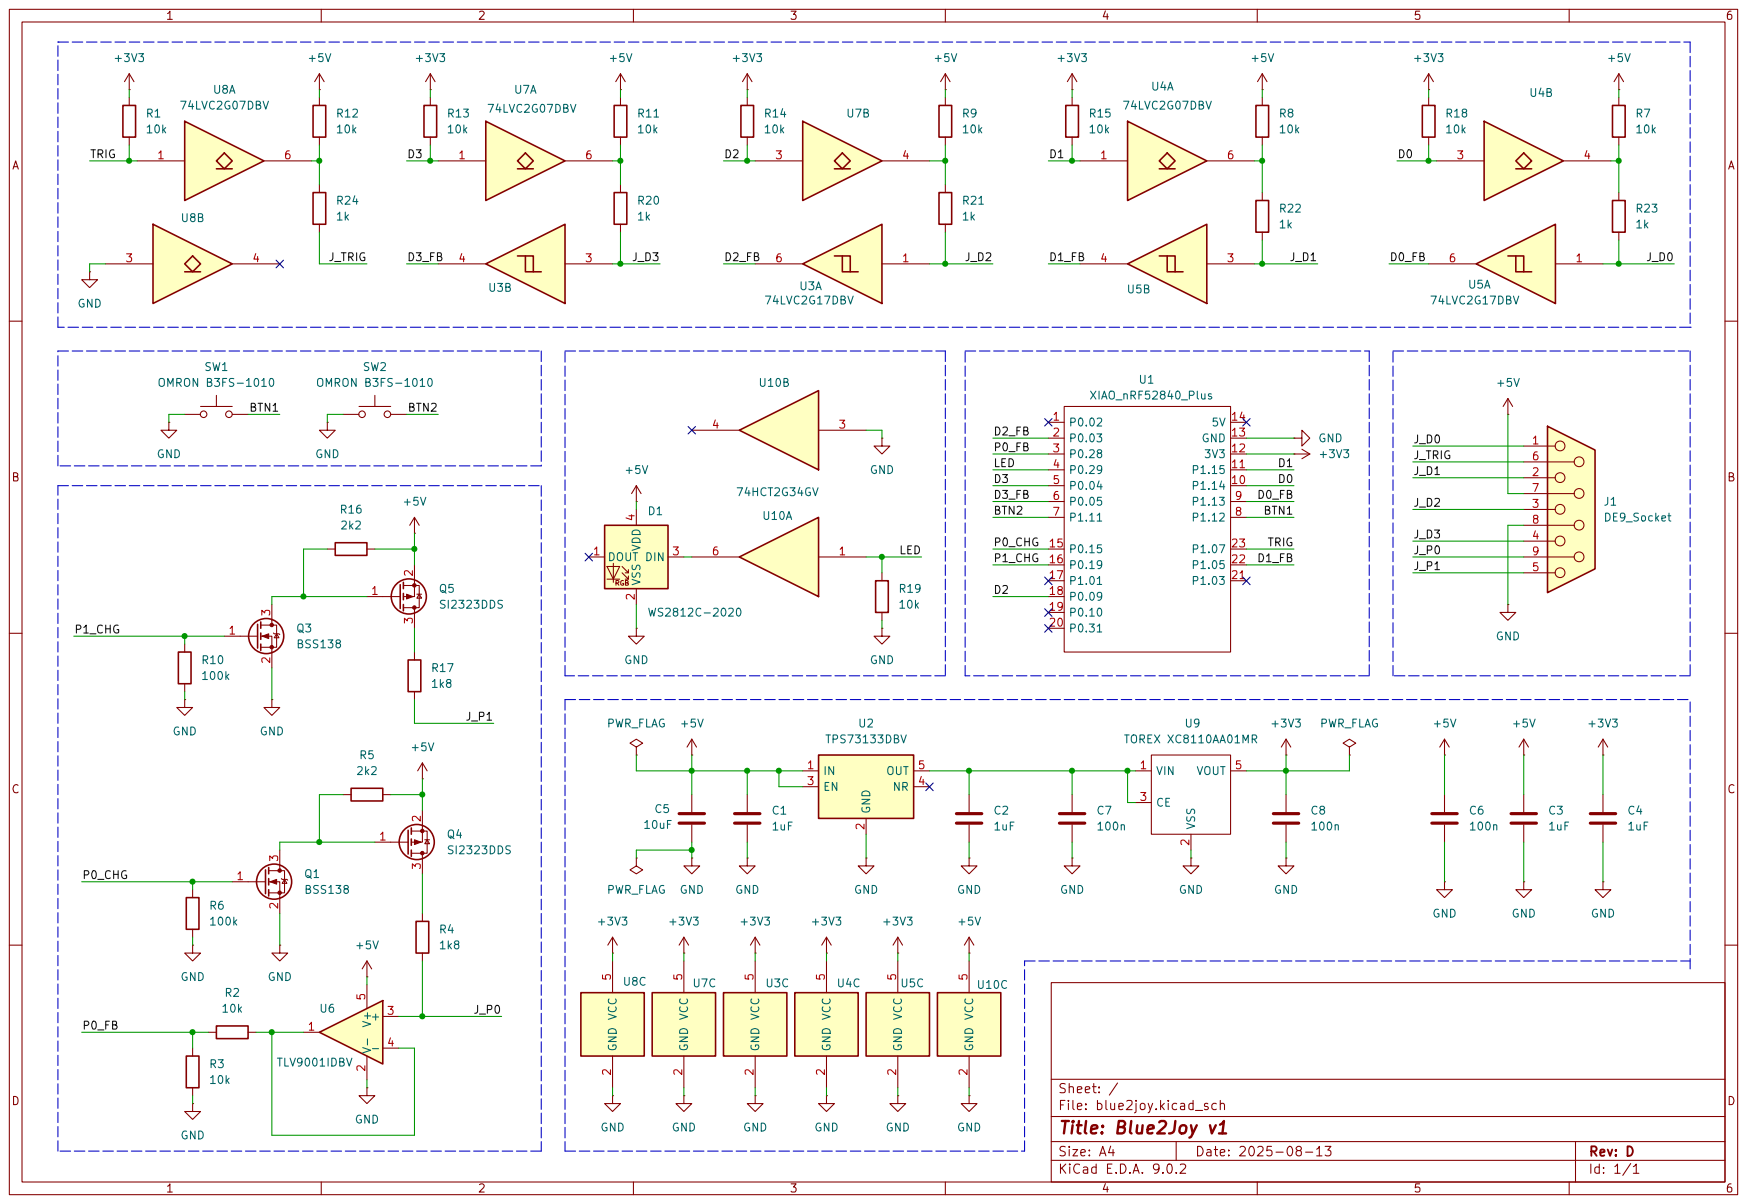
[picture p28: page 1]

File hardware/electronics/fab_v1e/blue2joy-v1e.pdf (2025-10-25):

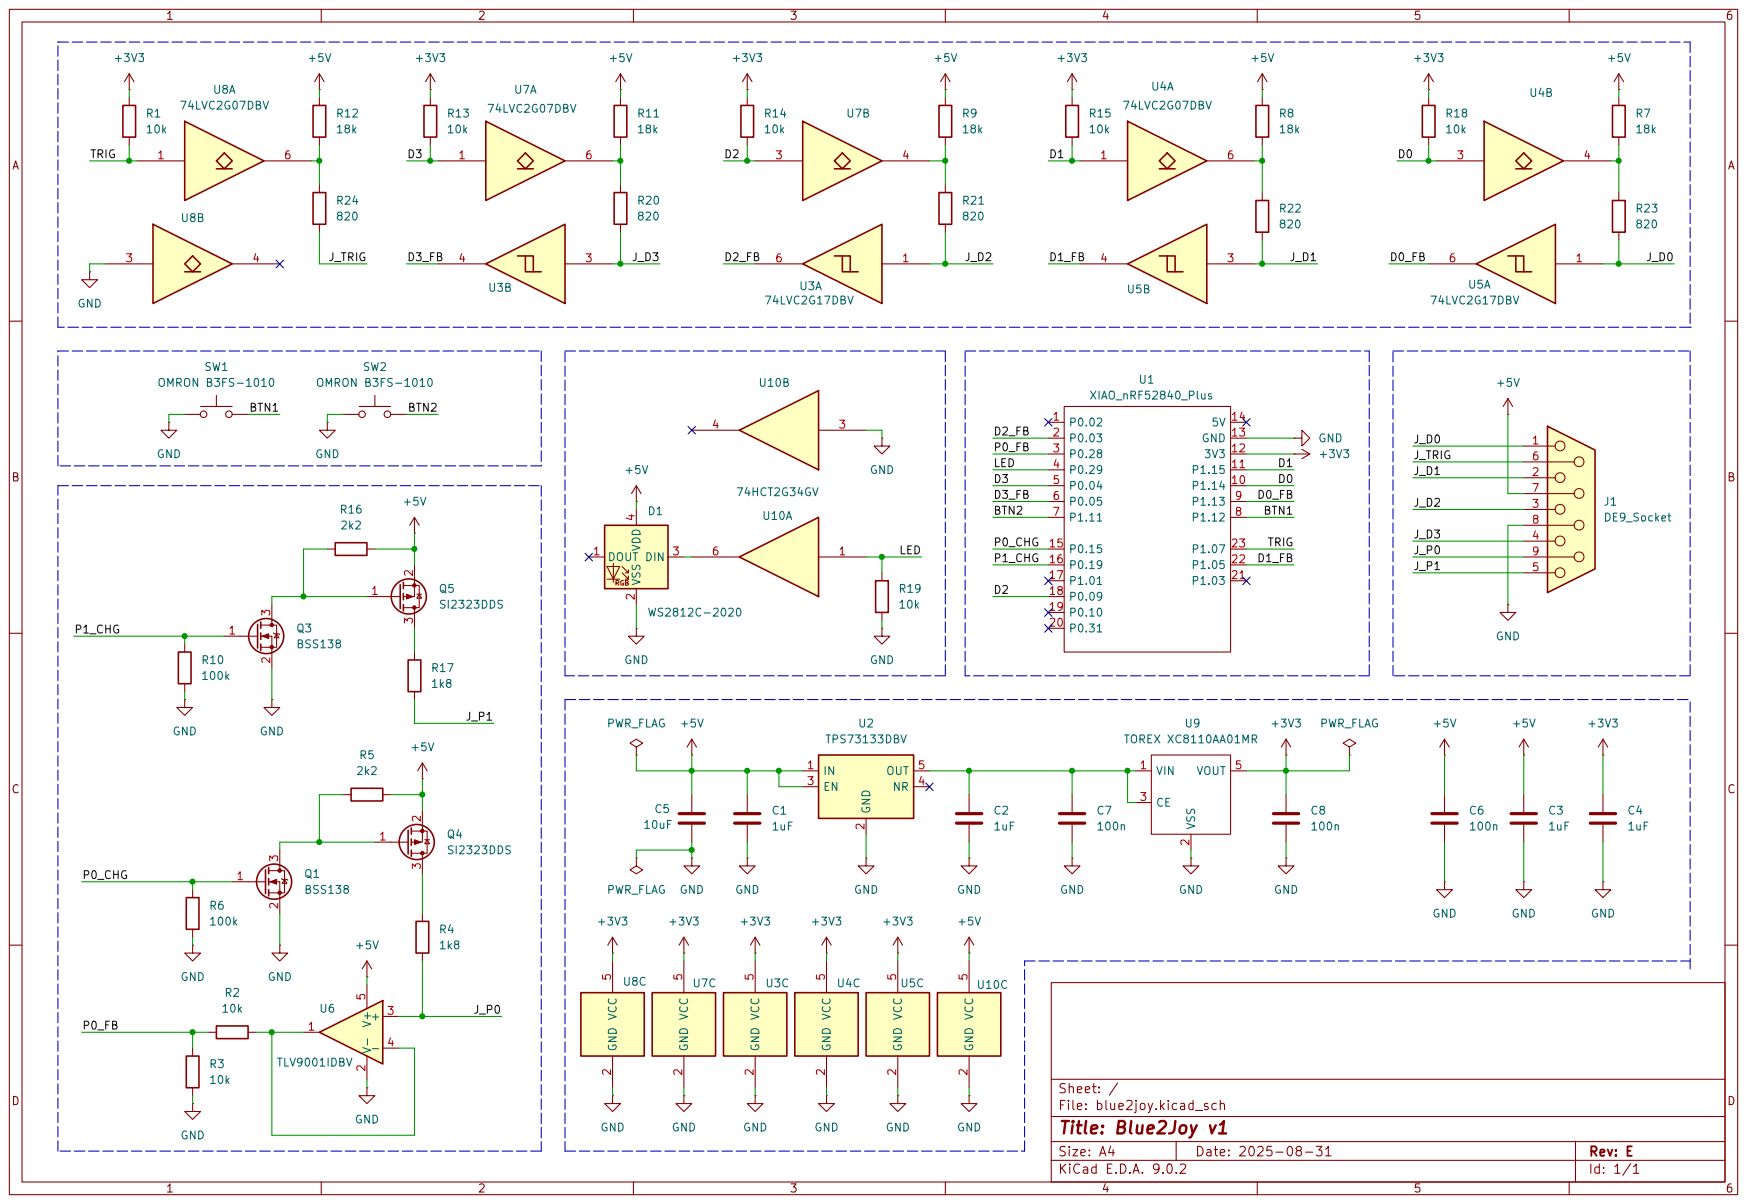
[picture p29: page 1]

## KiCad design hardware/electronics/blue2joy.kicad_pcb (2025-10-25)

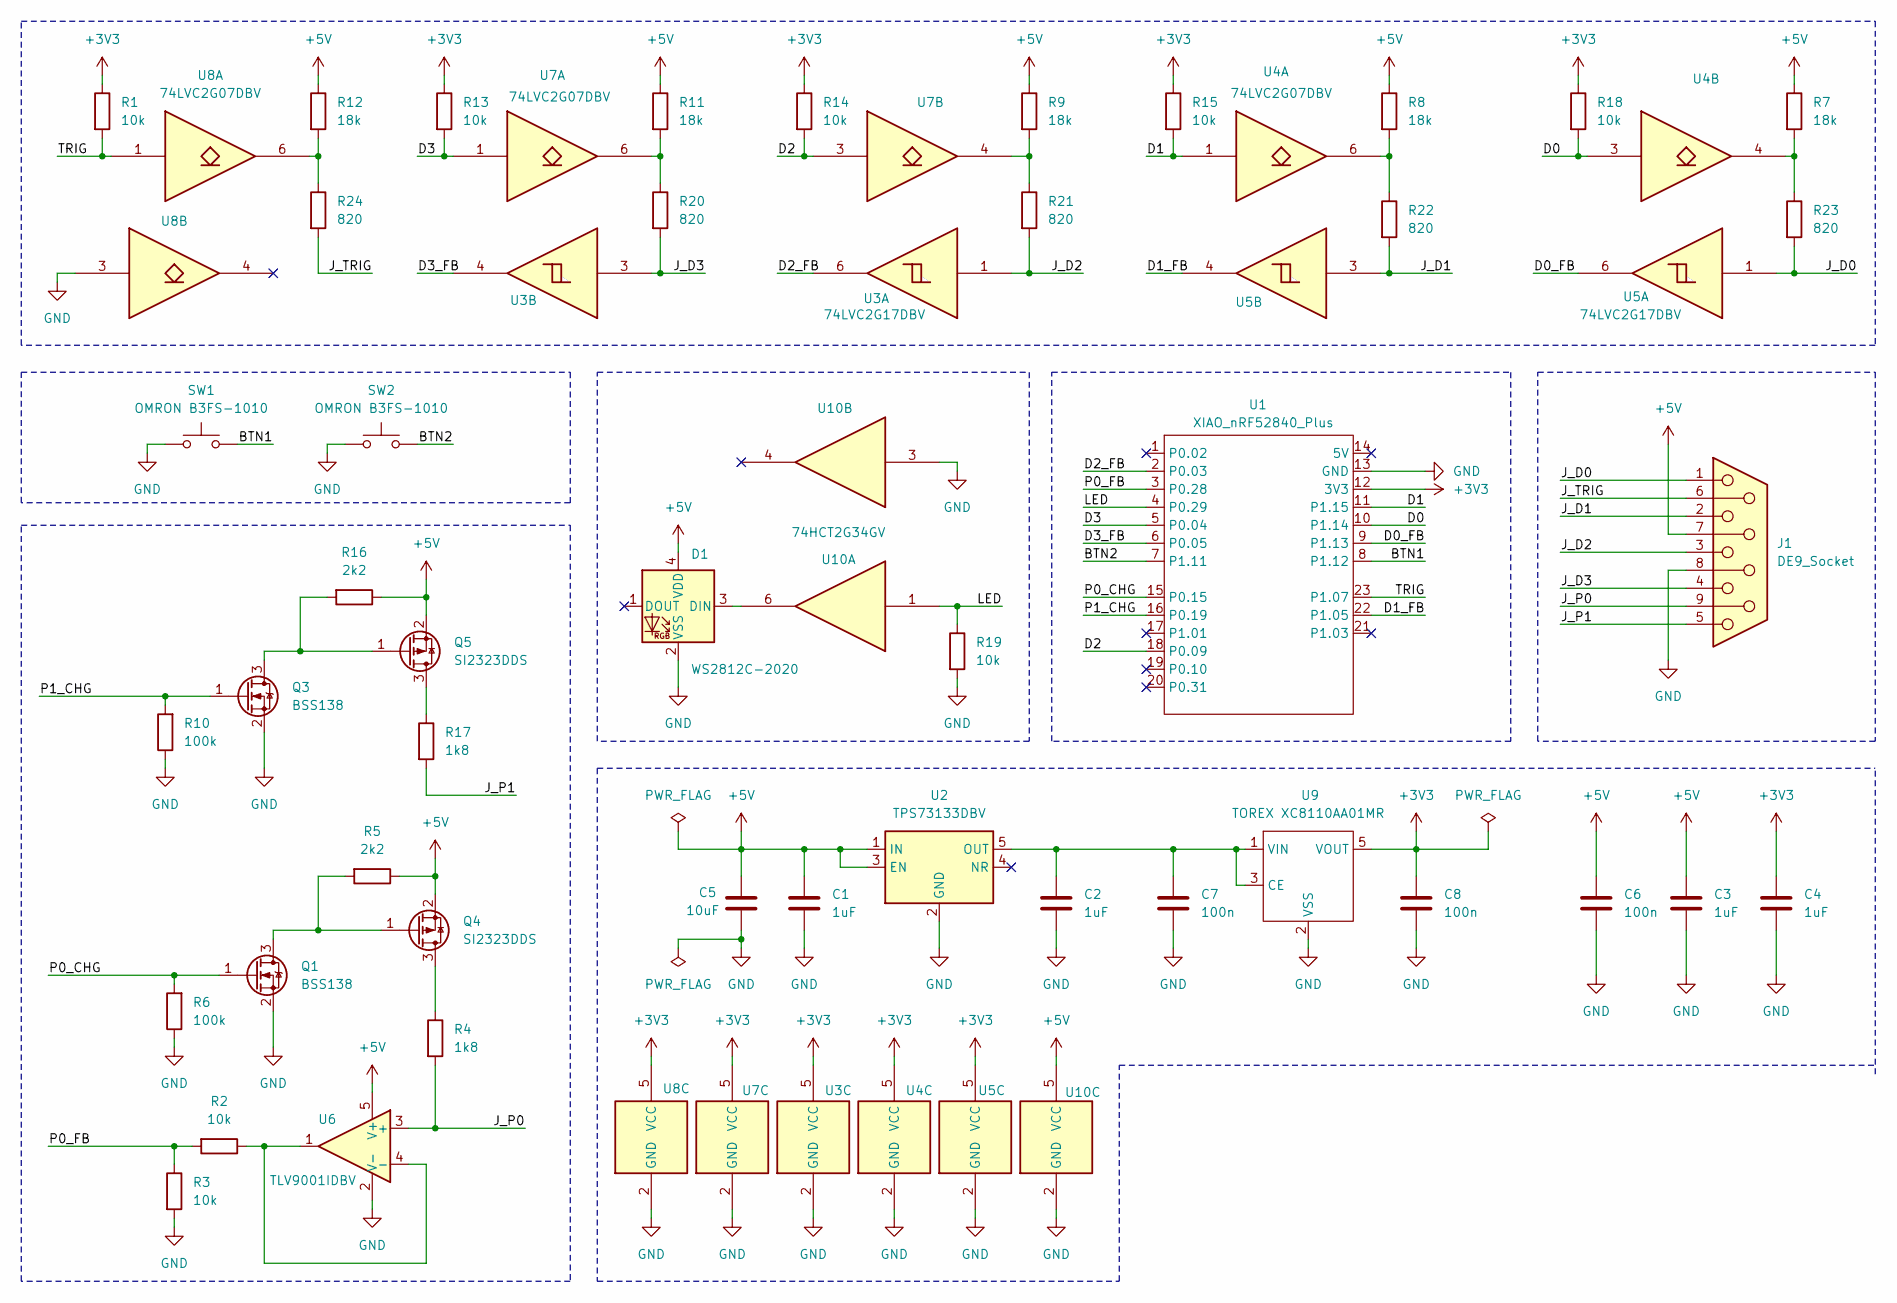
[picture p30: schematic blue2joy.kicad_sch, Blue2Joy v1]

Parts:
C1, C2, C3, C4: 1uF; C_0805_2012Metric
C5: 10uF; C_0805_2012Metric
C6, C7, C8: 100n; C_0805_2012Metric
D1: WS2812C-2020; LED_WS2812B-2020_PLCC4_2.0x2.0mm
J1: DE9_Socket; DSUB-9_Socket_EdgeMount_P2.77mm
Q1, Q3: BSS138; SOT-23
Q4, Q5: SI2323DDS; SOT-23
R1, R2, R3, R13, R14, R15, R18, R19: 10k; R_0805_2012Metric
R4, R17: 1k8; R_0805_2012Metric
R5, R16: 2k2; R_0805_2012Metric
R6, R10: 100k; R_0805_2012Metric
R7, R8, R9, R11, R12: 18k; R_0805_2012Metric
R20, R21, R22, R23, R24: 820; R_0805_2012Metric
SW1, SW2: OMRON B3FS-1010; SW_SPST_Omron_B3FS-100xP
U1: XIAO_nRF52840_Plus; XIAO-nRF52840-Plus-SMD
U2: TPS73133DBV; SOT-23-5
U3, U5: 74LVC2G17DBV; SOT-23-6
U4, U7, U8: 74LVC2G07DBV; SOT-23-6
U6: TLV9001IDBV; SOT-23-5
U9: TOREX XC8110AA01MR; SOT-23-5
U10: 74HCT2G34GV; SOT-23-6

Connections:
+3V3: C4.1, C8.1, R1.1, R13.1, R14.1, R15.1, R18.1, U1.12 (3V3), U3.5 (VCC), U4.5 (VCC), U5.5 (VCC), U7.5 (VCC), U8.5 (VCC), U9.5 (VOUT)
+5V: C1.1, C3.1, C5.1, C6.1, D1.4 (VDD), J1.7, Q4.2 (S), Q5.2 (S), R5.1, R7.1, R8.1, R9.1, R11.1, R12.1, R16.1, U2.1 (IN), U2.3 (EN), U6.5 (V+), U10.5 (VCC)
/BTN1: SW1.1, U1.8 (P1.12)
/BTN2: SW2.2, U1.7 (P1.11)
/D0: R18.2, U1.10 (P1.14), U4.3
/D0_FB: U1.9 (P1.13), U5.6
/D1: R15.2, U1.11 (P1.15), U4.1
/D1_FB: U1.22 (P1.05), U5.4
/D2: R14.2, U1.18 (P0.09), U7.3
/D2_FB: U1.2 (P0.03), U3.6
/D3: R13.2, U1.5 (P0.04), U7.1
/D3_FB: U1.6 (P0.05), U3.4
/J_D0: J1.1, R23.2, U5.1
/J_D1: J1.2, R22.2, U5.3
/J_D2: J1.3, R21.2, U3.1
/J_D3: J1.4, R20.2, U3.3
/J_P0: J1.9, R4.2, U6.3 (+)
/J_P1: J1.5, R17.2
/J_TRIG: J1.6, R24.2
/LED: R19.1, U1.4 (P0.29), U10.1
/P0_CHG: Q1.1 (G), R6.2, U1.15 (P0.15)
/P0_FB: R2.2, R3.1, U1.3 (P0.28)
/P1_CHG: Q3.1 (G), R10.2, U1.16 (P0.19)
/TRIG: R1.2, U1.23 (P1.07), U8.1
GND: C1.2, C2.2, C3.2, C4.2, C5.2, C6.2, C7.2, C8.2, D1.2 (VSS), J1.8, Q1.2 (S), Q3.2 (S), R3.2, R6.1, R10.1, R19.2, SW1.2, SW2.1, U1.13 (GND), U2.2 (GND), U3.2 (GND), U4.2 (GND), U5.2 (GND), U6.2 (V-), U7.2 (GND), U8.2 (GND), U8.3, U9.2 (VSS), U10.2 (GND), U10.3
unnamed: D1.3 (DIN), U10.6
unnamed: Q1.3 (D), Q4.1 (G), R5.2
unnamed: Q3.3 (D), Q5.1 (G), R16.2
unnamed: Q4.3 (D), R4.1
unnamed: Q5.3 (D), R17.1
unnamed: R11.2, R20.1, U7.6
unnamed: R12.2, R24.1, U8.6
unnamed: R9.2, R21.1, U7.4
unnamed: R8.2, R22.1, U4.6
unnamed: R7.2, R23.1, U4.4
unnamed: C2.1, C7.1, U2.5 (OUT), U9.1 (VIN), U9.3 (CE)
unnamed: R2.1, U6.1, U6.4 (-)

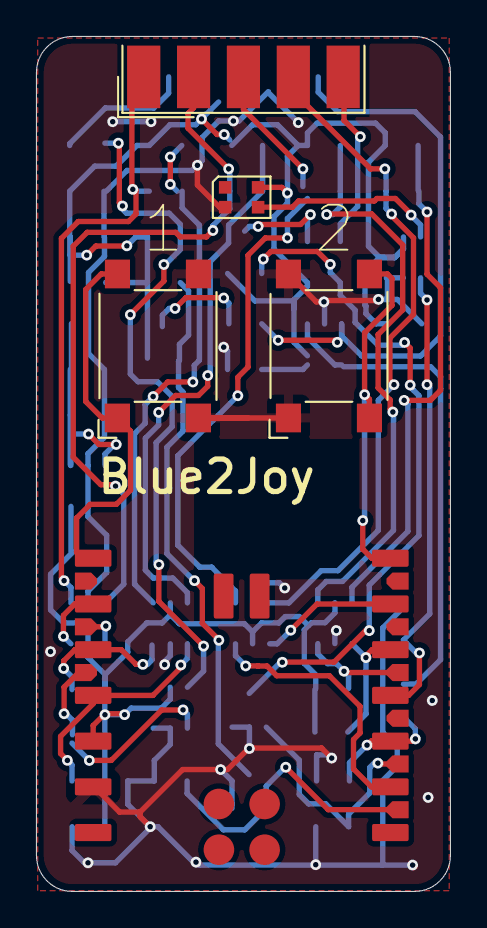
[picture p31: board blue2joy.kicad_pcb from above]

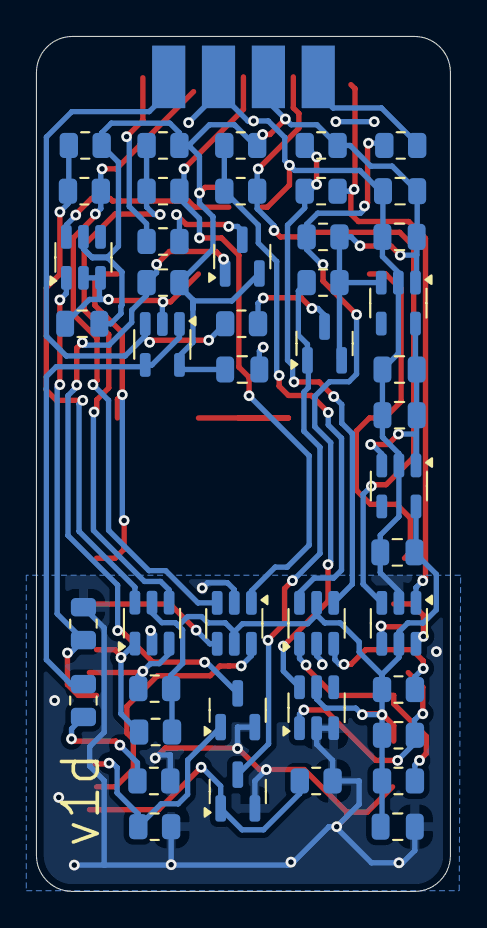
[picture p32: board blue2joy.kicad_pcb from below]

Board: 2 copper layers, 23.0 x 47.5 mm, 50 parts (45 on the bottom side), 37 nets.

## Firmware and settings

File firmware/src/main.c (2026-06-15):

/*
 * This file is part of the Blue2Joy project
 * (https://github.com/cepetr/blue2joy).
 * Copyright (c) 2025
 *
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
 * You should have received a copy of the GNU General Public License
 * along with this program. If not, see <http://www.gnu.org/licenses/>.
 */

#include <zephyr/bluetooth/bluetooth.h>
#include <zephyr/settings/settings.h>
#include <zephyr/storage/flash_map.h>

#include <zephyr/logging/log.h>
#include <app_version.h>

#include <bthid/bthid.h>
#include <btsvc/btsvc.h>
#include <usbsvc/usbsvc.h>
#include <io/buttons.h>
#include <io/rgbled_seq.h>
#include <io/io_pin.h>
#include <io/io_pot.h>
#include <io/spislave.h>
#include <mapper/mapper.h>
#include <mapper/profiles.h>
#include <mapper/joy_port.h>
#include <devmgr/devmgr.h>
#include <event/event_bus.h>
#include <xep80/xep80.h>
#include <usbd/usbd_init.h>

LOG_MODULE_REGISTER(btj, LOG_LEVEL_DBG);

static int erase_storage_partition(void)
{
    const struct flash_area *fa;
    int err = flash_area_open(FIXED_PARTITION_ID(storage_partition), &fa);
    if (err) {
        return err;
    }
    err = flash_area_erase(fa, 0, fa->fa_size); /* erase the whole partition */
    flash_area_close(fa);
    return err;
}

static void event_callback(void *context, const event_t *ev)
{
    if (ev->subject == EV_SUBJECT_SYS_STATE || ev->subject == EV_SUBJECT_DEV_LIST ||
        ev->subject == EV_SUBJECT_BTSVC_STATE) {
        devmgr_state_t state;
        devmgr_get_state(&state);

        if (btsvc_is_advertising()) {
            rgbled_set_state(led_seq_advertising);
        } else if (state.scanning) {
            if (state.mode == DEVMGR_MODE_PAIRING) {
                rgbled_set_state(led_seq_pairing);
            } else {
                rgbled_set_state(led_seq_scanning);
            }
        } else if (devmgr_is_connecting()) {
            rgbled_set_state(led_seq_connecting);
        } else if (devmgr_is_ready()) {
            rgbled_set_state(led_seq_ready);
        } else if (state.mode == DEVMGR_MODE_MANUAL) {
            rgbled_set_state(led_seq_manual);
        } else {
            rgbled_set_state(led_seq_idle);
        }
    } else if (ev->subject == EV_SUBJECT_CONN_ERROR) {
        rgbled_set_event(led_seq_error);
    }
}

int main(void)
{
    int err;

    LOG_INF("Blue2Joy %s", APP_VERSION_STRING);

    err = rgbled_init();
    if (err) {
        LOG_ERR("RGB LED init failed {err: %d}", err);
        return 0;
    }

    bool factory_reset = factory_reset_detected();

    if (factory_reset) {
        LOG_INF("Performing factory reset");
        err = erase_storage_partition();
        if (!err) {
            rgbled_set_event(led_seq_factory_reset);
        } else {
            LOG_ERR("Failed to erase storage partition {err: %d}", err);
        }
    }

    err = event_bus_init();
    if (err) {
        LOG_ERR("Event bus init failed {err: %d}", err);
        return 0;
    }

    err = event_bus_subscribe(event_callback, NULL);
    if (err) {
        LOG_ERR("Event bus subscribe failed {err: %d}", err);
        return 0;
    }

    err = io_pin_init();
    if (err) {
        LOG_ERR("io_pin driver init failed {err: %d}", err);
        return 0;
    }

    err = io_pot_init();
    if (err) {
        LOG_ERR("io_pot driver init failed {err: %d}", err);
        return 0;
    }

    err = mapper_init();
    if (err) {
        LOG_ERR("I/O mapper init failed {err: %d}", err);
        return 0;
    }

    err = xep80_init();
    if (err) {
        LOG_ERR("XEP80 init failed {err: %d}", err);
        return 0;
    }

    mapper_set_profile(0, &profile_joy_analog, false);
    // mapper_set_profile(0, &profile_mouse, false);

    err = bt_enable(NULL);
    if (err) {
        LOG_ERR("Bluetooth stack init failed {err: %d}", err);
        return 0;
    }

    err = devmgr_init();
    if (err) {
        LOG_ERR("Device manager init failed {err: %d}", err);
        return 0;
    }

    err = settings_load();
    if (err) {
        LOG_ERR("Failed to load settings {err: %d}", err);
    }

    err = usbsvc_init();
    if (err) {
        LOG_ERR("USB service init failed {err: %d}", err);
        return 0;
    }

    err = btsvc_init();
    if (err) {
        LOG_ERR("Bluetooth service init failed {err: %d}", err);
        return 0;
    }

    // Finally enable USB

    err = btj_usbd_init();
    if (err) {
        LOG_ERR("USB device init failed {err: %d}", err);
        return 0;
    }

    // joy_port_set_mode(JOY_PORT_MODE_UART);

    devmgr_set_mode(DEVMGR_MODE_AUTO, true);

    return 0;
}

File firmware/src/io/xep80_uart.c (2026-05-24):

/*
 * This file is part of the Blue2Joy project
 * (https://github.com/cepetr/blue2joy).
 * Copyright (c) 2025
 *
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
 * You should have received a copy of the GNU General Public License
 * along with this program. If not, see <http://www.gnu.org/licenses/>.
 */

#include <zephyr/irq.h>
#include <zephyr/kernel.h>
#include <zephyr/logging/log.h>

#include <nrfx_uart.h>
#include <nrfx_uarte.h>
#include <nrfx_pwm.h>
#include <hal/nrf_gpio.h>

#include "xep80_uart.h"

LOG_MODULE_REGISTER(btj_xep80_uart, LOG_LEVEL_DBG);

#define XEP_UART_TX_PIN NRF_GPIO_PIN_MAP(1, 15)
#define XEP_UART_RX_PIN NRF_GPIO_PIN_MAP(1, 13)

#define UART_BAUDRATE_BAUDRATE_Baud15625 (0x00400000UL)

typedef struct {
    uint16_t data[16];
    size_t tail;
    size_t head;
} tx_queue_t;

typedef struct {
    // UART instance for RX
    nrfx_uarte_t rx_uart;
    // PWM instance for TX
    nrfx_pwm_t tx_pwm;

    // Receive buffer
    uint8_t rx_buf[1];

    // Transmit queue
    tx_queue_t tx_queue;

    nrf_pwm_values_common_t tx_seq_vals[12]; // 1 start + 9 data + 2 stop
    nrf_pwm_sequence_t tx_seq;

    // Set if transmission is currently in progress
    bool tx_pending;

    // Next received byte has parity error
    bool parity_error;

    xep80_uart_rx_callback_t callback;
    void *callback_context;
} xep80_uart_t;

static xep80_uart_t g_xep80_uart;

// Forward declarations
static void xep80_rx_uart_event_handler(nrfx_uarte_event_t const *event, void *context);
static void xep80_tx_pwm_event_handler(nrfx_pwm_evt_type_t event_type, void *context);
static void xep80_uart_restart_rx(void);

int xep80_uart_init(xep80_uart_rx_callback_t callback, void *callback_context)
{
    xep80_uart_t *drv = &g_xep80_uart;

    memset(drv, 0, sizeof(xep80_uart_t));
    drv->callback = callback;
    drv->callback_context = callback_context;

    // XEP80 uses 9-bit UART communication, but the nRF52 UART peripheral does not
    // support 9-bit mode. Fortunatelly we can work around this limitation as follows:
    //
    // During reception, we use the parity bit to emulate the ninth bit. The ninth bit
    // is calculated from the parity of the first 8 bits and the parity error flag.
    //
    // During transmission, we cannot use UART at all since the nRF52 supports
    // only even parity so there's no way to set the parity bit to the desired value.
    // Instead, we use PWM peripheral and emulate the UART protocol with it.

    drv->rx_uart = (const nrfx_uarte_t)NRFX_UARTE_INSTANCE(0);

    nrfx_uarte_config_t rx_config = NRFX_UARTE_DEFAULT_CONFIG(NRF_UART_PSEL_DISCONNECTED, // TXD
                                                              XEP_UART_RX_PIN);           // RXD

    rx_config.baudrate = UART_BAUDRATE_BAUDRATE_Baud15625;
    rx_config.config.parity = NRF_UARTE_PARITY_INCLUDED;
    rx_config.config.stop = NRF_UARTE_STOP_ONE;

    if (nrfx_uarte_init(&drv->rx_uart, &rx_config, xep80_rx_uart_event_handler) != NRFX_SUCCESS) {
        LOG_ERR("UART init failed");
        return -EIO;
    }

    IRQ_CONNECT(NRFX_IRQ_NUMBER_GET(NRF_UARTE_INST_GET(0)), IRQ_PRIO_LOWEST,
                NRFX_UARTE_INST_HANDLER_GET(0), 0, 0);

    // This call is needed to avoid automatically stopping reception on error
    nrfx_uarte_rx_enable(&drv->rx_uart, 0);

    // Start reception
    xep80_uart_restart_rx();

    drv->tx_pwm = (const nrfx_pwm_t)NRFX_PWM_INSTANCE(0);

    nrfx_pwm_config_t cfg =
        NRFX_PWM_DEFAULT_CONFIG(XEP_UART_TX_PIN, NRF_PWM_PIN_NOT_CONNECTED,
                                NRF_PWM_PIN_NOT_CONNECTED, NRF_PWM_PIN_NOT_CONNECTED);

    cfg.base_clock = NRF_PWM_CLK_16MHz;
    cfg.top_value = 16000000 / 15625; // 1024
    cfg.count_mode = NRF_PWM_MODE_UP;
    cfg.load_mode = NRF_PWM_LOAD_COMMON;
    cfg.step_mode = NRF_PWM_STEP_AUTO;

    if (nrfx_pwm_init(&drv->tx_pwm, &cfg, xep80_tx_pwm_event_handler, drv) != NRFX_SUCCESS) {
        LOG_ERR("PWM init failed");
        nrfx_uarte_uninit(&drv->rx_uart);
        return -EIO;
    }

    IRQ_CONNECT(NRFX_IRQ_NUMBER_GET(NRF_PWM_INST_GET(0)), IRQ_PRIO_LOWEST,
                NRFX_PWM_INST_HANDLER_GET(0), 0, 0);

    drv->tx_seq.values.p_common = drv->tx_seq_vals;
    drv->tx_seq.length = ARRAY_SIZE(drv->tx_seq_vals);
    drv->tx_seq.repeats = 0;
    drv->tx_seq.end_delay = 0;

    nrf_gpio_pin_set(XEP_UART_TX_PIN);

    return 0;
}

void xep80_uart_set_txd(bool high)
{
    if (high) {
        nrf_gpio_pin_set(XEP_UART_TX_PIN);
    } else {
        nrf_gpio_pin_clear(XEP_UART_TX_PIN);
    }
}

void xep80_uart_uninit(void)
{
    xep80_uart_t *drv = &g_xep80_uart;

    nrfx_uarte_uninit(&drv->rx_uart);
    nrfx_pwm_uninit(&drv->tx_pwm);

    // Return TX pin to GPIO so it can be used by regular joystick output logic
    nrf_gpio_cfg_output(XEP_UART_TX_PIN);
    nrf_gpio_pin_set(XEP_UART_TX_PIN);
}

static bool tx_queue_write(tx_queue_t *q, uint16_t word)
{
    size_t next_tail = (q->tail + 1) % ARRAY_SIZE(q->data);

    if (next_tail == q->head) {
        // Queue is full
        return false;
    }

    q->data[q->tail] = word;
    q->tail = next_tail;

    return true;
}

static bool tx_queue_read(tx_queue_t *q, uint16_t *word)
{
    if (q->head == q->tail) {
        // Queue is empty
        return false;
    }

    *word = q->data[q->head];
    q->head = (q->head + 1) % ARRAY_SIZE(q->data);

    return true;
}

static void xep80_uart_restart_tx(xep80_uart_t *drv);

static void xep80_tx_pwm_event_handler(nrfx_pwm_evt_type_t event_type, void *context)
{
    xep80_uart_t *drv = (xep80_uart_t *)context;

    if (event_type == NRFX_PWM_EVT_STOPPED) {
        drv->tx_pending = false;
        // Start next transmission
        xep80_uart_restart_tx(drv);
    }
}

static inline uint16_t duty_for_level(bool high)
{
    return high ? 0 : 1024;
}

static void xep80_uart_restart_tx(xep80_uart_t *drv)
{
    uint16_t word;

    if (!tx_queue_read(&drv->tx_queue, &word)) {
        // No more data to send
        return;
    }

    nrf_pwm_values_common_t *vals = drv->tx_seq_vals;

    // Encode 9-bit words into a pwm sequence according to the UART protocol:
    //
    // Start bit (1) + Data bits (8) + 9th bit (1) + Stop bits (2) = 12 bits

    vals[0] = duty_for_level(false); // Start bit

    for (int i = 0; i < 9; i++) {
        vals[i + 1] = duty_for_level((word & 0x1) != 0);
        word >>= 1;
    }

    vals[10] = duty_for_level(true); // Stop bit 1
    vals[11] = duty_for_level(true); // Stop bit 2

    drv->tx_pending = true;

    nrfx_pwm_simple_playback(&drv->tx_pwm, &drv->tx_seq, 1, NRFX_PWM_FLAG_STOP);
}

int xep80_uart_send(uint16_t word)
{
    xep80_uart_t *drv = &g_xep80_uart;

    unsigned int key = irq_lock();

    if (!tx_queue_write(&drv->tx_queue, word)) {
        // Queue is full, drop the word
        irq_unlock(key);
        return -ENOMEM;
    }

    if (!drv->tx_pending) {
        xep80_uart_restart_tx(drv);
    }

    irq_unlock(key);

    return 0;
}
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

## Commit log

2025-10-25 fix scan dialog button
2025-10-25 Add profile change, device delete
2025-10-25 Add connect button
2025-10-26 refactor pin and pot editors
2025-10-26 conditional pin config
2025-10-26 pin/pot header of the left
2025-10-26 simplify pin/pot editors
2025-10-28 detect disconnected device
2025-10-28 disconnect device when deleted
2025-10-28 add start/stop advertising button
2025-10-28 refactor device-view
2025-10-28 update 3d files
    [blue2joy_base_v1.3mf, blue2joy_button_left_v1.3mf, blue2joy_button_right_v1.3mf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]
2025-10-30 update timer cc in interrupt
2025-10-30 configure rc oscillator calibration
2025-11-02 add quadrature encoders
2025-11-15 centralize device scanning logic in BtjModel
2025-11-15 add list of compatible devices
2026-01-10 improve pin/pot editor layout
2026-01-10 update the list of compatible devices
2026-01-17 improve mapper, introduce integrators, analog encoders
2026-01-23 refactor filtering logic in hid-usage-select
2026-01-23 indicate the device state using icons
2026-01-25 feat: improve pot accuracy and decrease jitter
    [io_pot.c]
2026-02-28 feat: implement uart driver for xep80
2026-04-25 fix: handle case when no HID report characteristics are discovered
2026-04-25 refactor: advance xep80 tx queue on PWM stopped event
2026-04-25 fix: preserve device order when importing settings
2026-04-26 fix: fix device state update
2026-04-26 feat: add webusb device
2026-05-30 fix: fix raise conditions in webusb
    [main.c]
2026-05-30 fix(core): remove unnecessary synchronization
    [xep80.c]
2026-05-31 fix: fix xep80 state synchronization
    [btjp_msg.h]
2026-06-05 feat(web): improve error state UI and reconnect flow
2026-06-06 refactor(web): extract xep80 shared frame decode logic
2026-06-06 refactor(web): introduce frame controller
2026-06-06 chore(web): rename FrameBuffer to Frame
2026-06-06 feat(web): use icons instad of buttons in navbar
2026-06-06 feat(web): improve icons/buttons in device-view
2026-06-06 feat(web): align connect buttons
2026-06-14 feat(btjkbd): add kb driver emulating keystrokes from paddle analog input
2026-06-15 fix(web): copy only current BLE notification payload bytes
2026-06-15 fix(web): clear advertised devices before scanning
2026-06-15 fix(firrmware): auto connect with bonded devices
2026-06-15 fix(firmware): defer device entry creation until address resolution
2026-06-15 fix(firmware): keep report map ATT read params in device struct
2026-06-15 fix(firmware): track report_ref reads by index in device struct
2026-06-15 fix(firmware): fix OOB read in single-element LED sequences
    [main.c]

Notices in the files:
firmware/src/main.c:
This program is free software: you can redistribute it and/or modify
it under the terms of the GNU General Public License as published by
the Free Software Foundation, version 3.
